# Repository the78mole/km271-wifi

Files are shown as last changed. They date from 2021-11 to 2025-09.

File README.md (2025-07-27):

# KM271-WiFi (WiFi enabled replacement for the KM271)

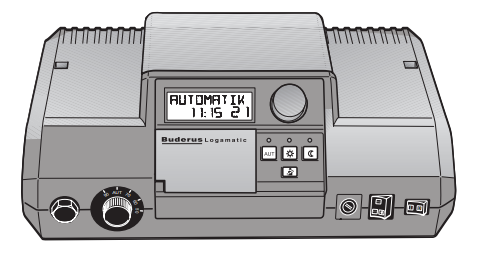
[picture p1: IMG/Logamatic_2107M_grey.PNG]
Buderus Logamatic 2107 M grey


    
    

If you just received a module, you can find help with installation here:

  - [Getting Started Guide](DOC/Getting_Started.md)
  - [Erste Schritte](DOC/Erste_Schritte.md)

This piece of hardware is a direct replacement for the Buderus KM271 to control a buderus heating system with Logamatic 2107 controller board. Maybe other controllers are supported. Please file an issue (or better a PR) if you have my module running in other Buderus heating controllers, so I can add them here.

This hardware and its documentation is released under the *TAPR Open Hardware License* Version 1.0 (May 25, 2007). 
A [copy of the license](LICENSE.txt) is included here or can be accessed in multiple formats on [tapr.org](https://tapr.org/the-tapr-open-hardware-license/). 

For more details, have a look in the:

  * [hardware description](DOC/Hardware%20Description.md)
  * [interactive BOM](https://htmlpreview.github.io/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)

If you bought the board in my tindie store, you could find a how-to to get it running [here](https://the78mole.de/projects/km271-wifi-howto/)

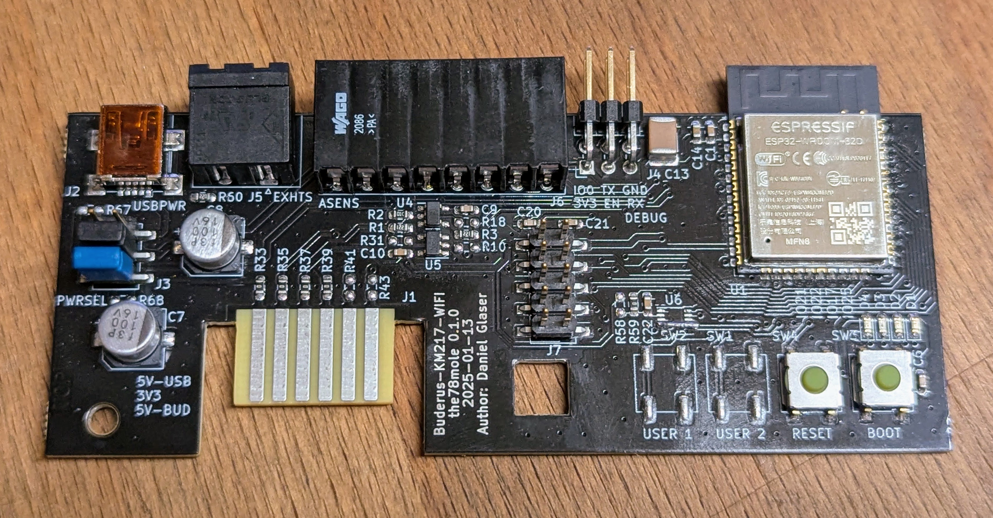
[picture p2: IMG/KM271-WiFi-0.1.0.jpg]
KM271-WiFi_0.1.0


## Extensions

There is now an Extension to add wired Ethernet to the board. The prototype already works, availability in tindie store will still take some time...

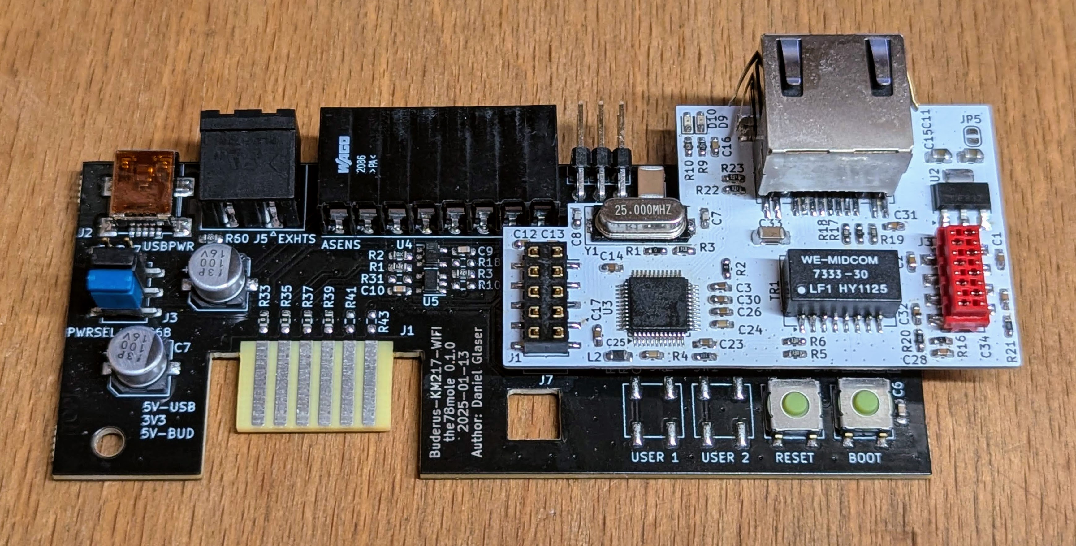
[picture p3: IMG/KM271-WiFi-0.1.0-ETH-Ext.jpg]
KM271-WiFi_0.1.0_ETH-Ext


## Improvements / ToDo

 * Add a OneWire temperature Sensor on the board itself
 * Fix a minor bug with external I2C pull-up (tie them to PCA9306 selectable supply)

## Firmware Management

This project includes a comprehensive firmware management system for easy firmware updates and batch production:

### 🚀 Quick Start

```bash
cd FW
./setup-dev.sh                                    # Setup development environment
uv run scripts/flash_firmware.py                  # List available firmware
uv run scripts/flash_firmware.py blinkenlights    # Flash single device
```

### 📦 Available Firmware Options

- **blinkenlights** - Local PlatformIO test project for hardware validation  
- **km271-esphome** - ESPHome-based KM271 WiFi replacement ([the78mole/ESPhome-KM271-WiFi](https://github.com/the78mole/ESPhome-KM271-WiFi))
- **dewenni-km271** - Feature-rich KM271 firmware ([dewenni/ESP_Buderus_KM271](https://github.com/dewenni/ESP_Buderus_KM271))

All firmware images are automatically downloaded and prepared for flashing using the management scripts.

### 🏭 Batch Production

For manufacturing multiple units:

```bash
uv run scripts/flash_firmware.py blinkenlights --loop
```

- Flash device → Connect next device → Press any key to continue
- Press 'n' to stop and show statistics
- Supports both ESC and 'n' for stopping

### 📖 Documentation

See [`FW/README.md`](FW/README.md) for detailed firmware management documentation, including:

- Setup instructions
- Script usage examples  
- Troubleshooting guide
- Batch production workflows

## 5V Supply Calibration

I decided to set the multiplier very far off the actual value, to make it clear, that you need to calibrate it due to the inaccurate/bad design of the ESP32 ADC with a quite low input impedance and general error.
To calibrate the Buderus 5V voltage monitor, you need to first find out the YAML section of your ESPhome device. It should look like the following:

```yaml
  - platform: adc
    pin: 36
    unit_of_measurement: "V"
    name: "KM217 5V Supply"
    accuracy_decimals: 2
    update_interval: 5s
    attenuation: 6dB
    filters:
      - multiply: 28.1826
      - throttle_average: 60s
```

Now look at the readout of your sensor, say it is 47.3V and measure the real voltage of the 5V supply (e.g. Pin 1 to 7 on the sensor header), say you measure 4.9V. Use the multiplier from your YAML and do the following calculation:

    4.9V / 47.3V * 28.1826 = 2.9196

Replace the multiplier by the calculated value and you will get more exact values, close to the 5V.

## Additional Information

  - [Moles Blog - Reverse Engineering KM271](https://the78mole.de/reverse-engineering-the-buderus-km217/)
  - [Moles Blog - KM271-WiFi Project](https://the78mole.de/projects/km271-wifi-howto/)
  - [KM271-WiFi ESPhome Project (GitHub)](https://github.com/the78mole/ESPhome-KM271-WiFi)
  - [KM271-WiFi WebTools (Flashing)](https://the78mole.github.io/ESPhome-KM271-WiFi/)
  - [KM271-Firmware ESPhome Component (GitHub)](https://github.com/the78mole/esphome_components)

You can buy the module on [Tindie](https://www.tindie.com/products/the78mole/buderus-km217-wifi-replacement/) (if available).

## Star History

Star History Chart (https://www.star-history.com/#the78mole/km271-wifi&Date)

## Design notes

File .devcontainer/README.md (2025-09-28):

# KM217 Hardware Development Environment

This DevContainer provides a complete hardware development environment for the KM217 project using a pre-built Docker image for optimal performance and fast startup.

## 🚀 Quick Start

1. Open this folder in VS Code
2. Click "Reopen in Container" when prompted
3. Container starts in ~30 seconds using `ghcr.io/the78mole/kicaddev:1.6.0`

## ✨ Features Included

- **KiCad 9.0.3**: Latest PCB design tools with full library support
- **Python 3.12.3**: Complete development environment with hardware packages
- **PCB Tools**: PCBDraw for visualization, KiKit for panelization
- **Development**: Git, VS Code extensions, debugging tools
- **GUI Support**: X11 forwarding for native KiCad GUI experience

## 🏗️ DevContainer Structure

```
.devcontainer/
├── devcontainer.json        # Main configuration
├── README.md               # This documentation
├── STATUS.md               # Current status and notes
└── test-devcontainer.sh    # Validation script
```

## � Available Tools

### KiCad 9.0.3 Suite
- **Schematic Editor**: Complete circuit design
- **PCB Editor**: Layout with advanced routing
- **3D Viewer**: Realistic board visualization
- **Symbol/Footprint Libraries**: Comprehensive component database

### Python Development
- **Python 3.12.3**: Latest stable Python
- **PCBDraw**: PCB visualization and documentation
- **KiKit**: PCB panelization and production automation
- **Hardware Libraries**: GPIO, I2C, SPI development tools

### Development Environment
- **Git**: Version control with full history
- **VS Code Extensions**: Python, Markdown, Linting pre-configured
- **X11 GUI**: Native Linux GUI application support

## 🚀 Usage Examples

### KiCad Development
```bash
# Open KiCad schematic editor
kicad myproject.kicad_pro

# Generate production files
kicad-cli pcb export gerbers --output production/ myproject.kicad_pcb

# Export schematic PDF
kicad-cli sch export pdf --output schematic.pdf myproject.kicad_sch
```

### PCB Visualization
```bash
# Create assembly diagram
pcbdraw myproject.kicad_pcb assembly.svg --side front

# Generate production visualization
pcbdraw myproject.kicad_pcb production.png --style builtin:set-blue-hasl
```

### PCB Panelization
```bash
# Create 2x2 panel with 2mm spacing
kikit panelize grid --space 2mm --gridsize 2x2 single.kicad_pcb panel.kicad_pcb
```
- **ImageMagick**: Image processing

## 📁 Directory Structure

The container sets up the following directories:
- `~/Documents/Hardware/` - Hardware projects
- `~/Documents/PCB/` - PCB designs  
- `~/Documents/Datasheets/` - Component datasheets
- `~/Documents/3D-Models/` - 3D model files
- `~/Templates/` - Document templates

## 🔧 VS Code Extensions

Pre-installed extensions for optimal workflow:
- Python development tools
- Markdown editing and preview
- Markdown PDF export
- YAML/JSON editing
- Jupyter notebook support

## 🚀 Getting Started

### Option 1: VS Code DevContainer (Recommended)
1. Open this project in VS Code
2. Install the "Dev Containers" extension
3. When prompted, click "Reopen in Container"
4. Wait for the container to build (first time only)
5. Start developing!

### Option 2: Local Docker Build
```bash
# Build the container locally
.devcontainer/build.sh

# Run manually
docker run -it --rm -v $(pwd):/workspaces hw-dev-container
```

### Quick Test
```bash
# Test Markdown to PDF conversion
cd ~/Templates
~/markdown2pdf.sh sample_hardware_doc.md

## 📋 Requirements

- Docker installed and running
- VS Code with Dev Containers extension
- X11 forwarding for GUI applications (automatically configured)

## ⚡ Performance

- **Startup Time**: ~30 seconds
- **Image Size**: 9.12GB (optimized)
- **Base System**: Ubuntu 24.04 LTS
- **Last Updated**: Regularly maintained

## 🔍 Troubleshooting

### GUI Applications Not Starting
If KiCad GUI doesn't open:
```bash
# Verify X11 forwarding
echo $DISPLAY

# Check if display is available
xdpyinfo | head
```

### Permission Issues
```bash
# Fix workspace permissions if needed
sudo chown -R vscode:vscode /workspaces
```

### Container Issues
```bash
# Test container functionality
./.devcontainer/test-devcontainer.sh

# Rebuild if needed
Docker: Rebuild Container (Ctrl+Shift+P)
```

## 📚 Additional Resources

- [KiCad Documentation](https://docs.kicad.org/)
- [PCBDraw Documentation](https://github.com/yaqwsx/pcbdraw)
- [KiKit Documentation](https://github.com/yaqwsx/kikit)

---

*Happy hardware development! 🛠️*

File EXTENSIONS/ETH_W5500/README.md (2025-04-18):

# Ethernet Module W5500

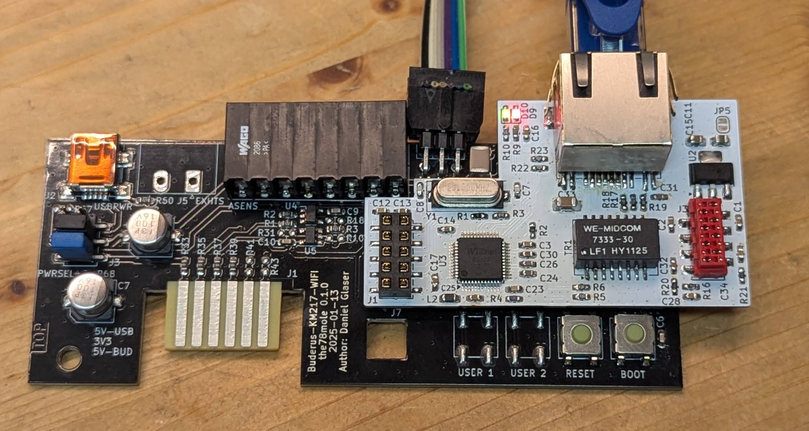
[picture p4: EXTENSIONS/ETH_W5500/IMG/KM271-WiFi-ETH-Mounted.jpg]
Extension mounted


The extension itself looks like this:

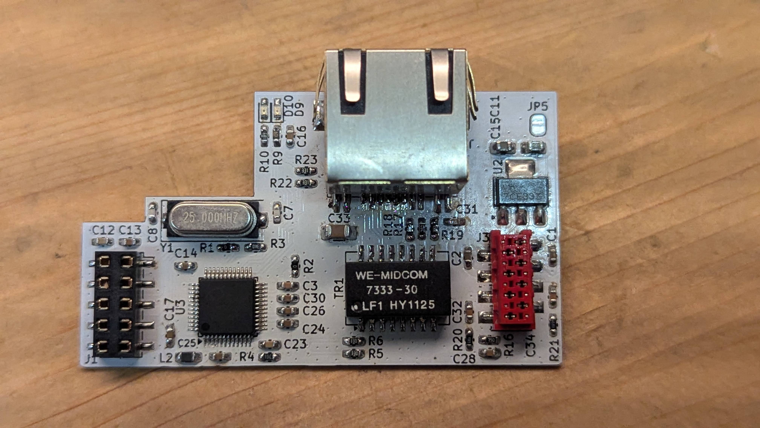
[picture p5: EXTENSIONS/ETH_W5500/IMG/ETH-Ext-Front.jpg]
ETH-Ext-Front

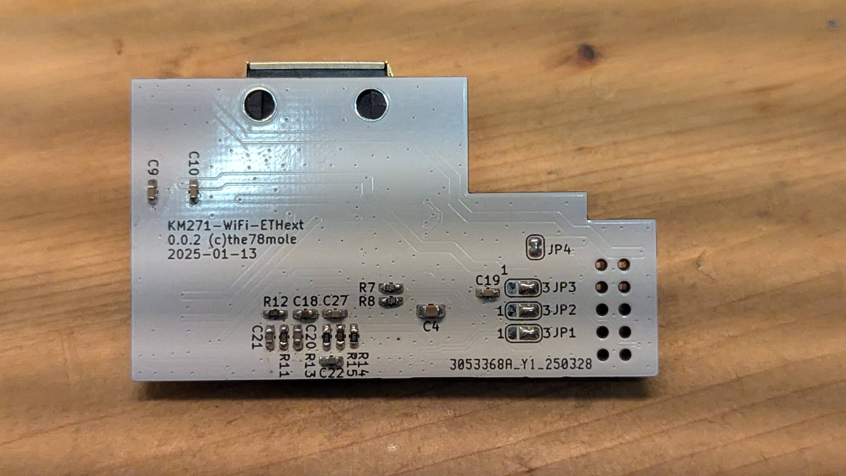
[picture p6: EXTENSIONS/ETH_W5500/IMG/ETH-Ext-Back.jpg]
ETH-Ext-Back


## Intro

To achieve wired connectivity with the KM271-WiFi (e.g. in concrete basements without any WiFi), we decided to
develop an Ethernet-Extension module, that is attached on the EXT (J7) connector via SPI interface.

For KM271-WiFi 0.1.0, you need to add a tiny fix-bridge to make it working.

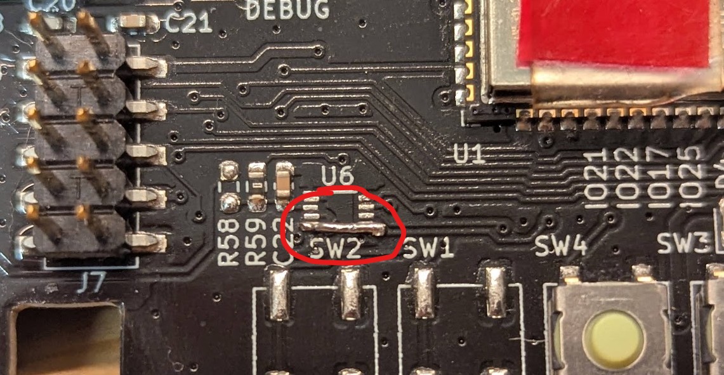
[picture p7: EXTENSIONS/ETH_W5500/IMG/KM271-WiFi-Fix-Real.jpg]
Fix-Bridge

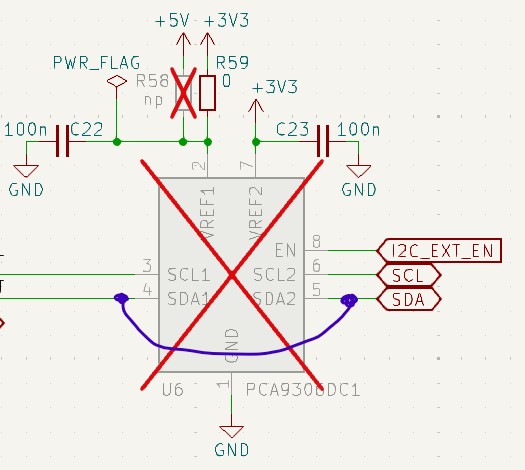
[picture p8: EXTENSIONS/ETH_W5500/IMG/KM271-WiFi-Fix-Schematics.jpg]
Fix-Schematic


Alternatively, when not experienced with soldering, you can add a wire to the ESP and the connector foot, but you need to use an insulated one:

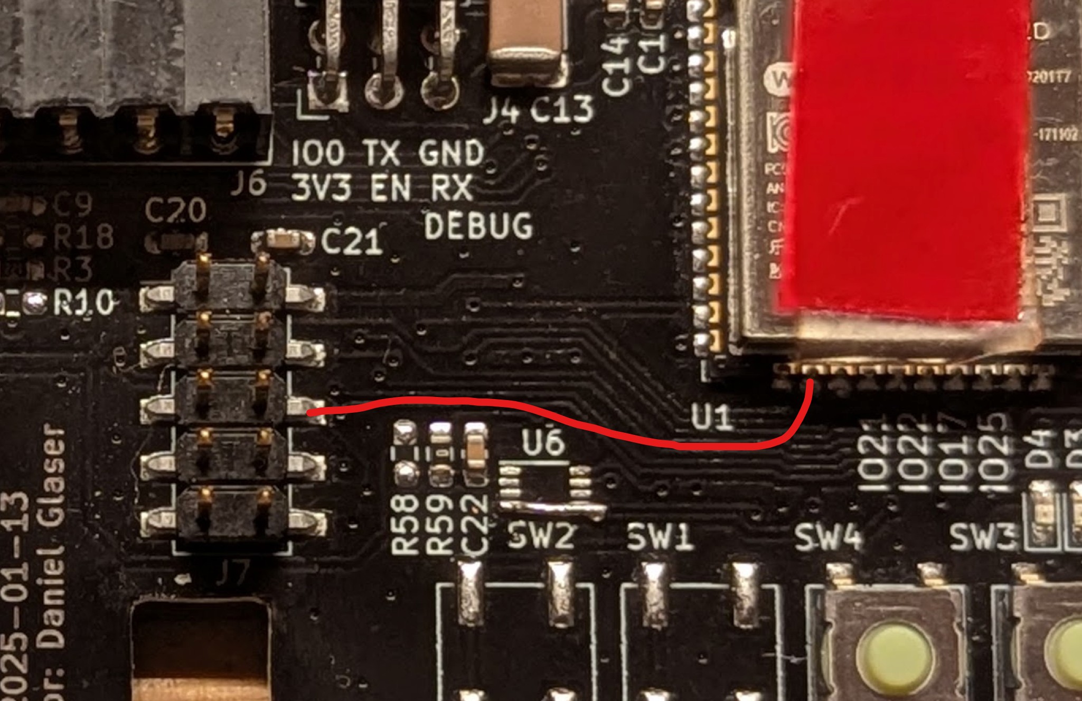
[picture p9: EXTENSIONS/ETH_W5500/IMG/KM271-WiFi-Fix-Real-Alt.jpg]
Fix-Wire


While it is also possible to connect a W5500 Ethernet module to the Board or a generic ESP32 using Du-Pont wires
it is not suggested due to instable operation.

## ETH-Ext Module: 

### Installation

The module needs to be mechanically fixed to and electrically insulated well from the KM271-WiFi. The space is quite dense and the easiest option is, to use some acrylic adhesive to attach it to the ESP32-WROOM-Module.

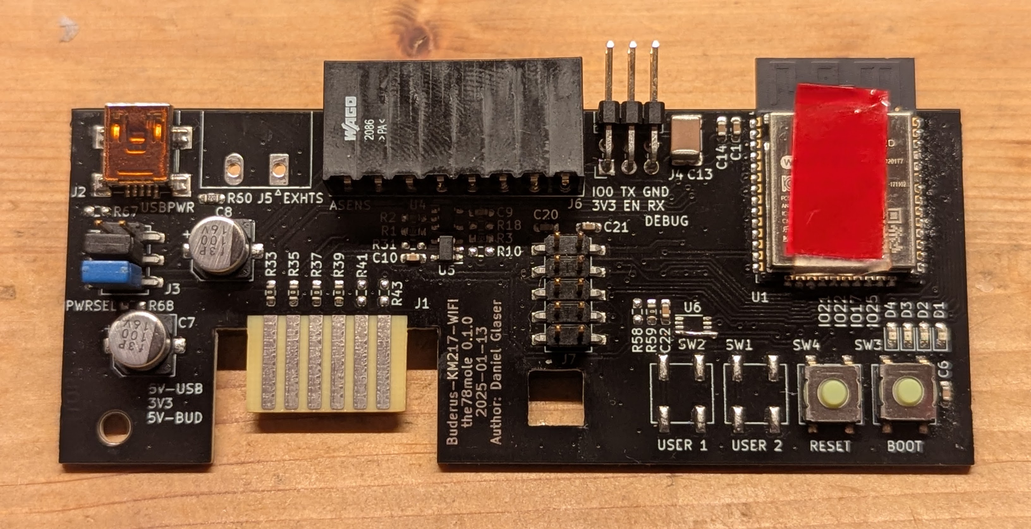
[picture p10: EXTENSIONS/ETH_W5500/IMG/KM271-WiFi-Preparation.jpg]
Prep KM271-WiFi


When ordering the ETH-Extension from Tindie, there is already an adhesive attached to the bootom of the Extension. Just remove the protective foil and mount it on the KM271-WiFi.

### ESPhome

For ESPhome, you need to add some configuration to the ESPhome YAML file:

```yaml
# Example configuration entry for SPI chips
ethernet:
  type: W5500
  clk_pin: 18
  mosi_pin: 23
  miso_pin: 19
  cs_pin: 15
  interrupt_pin: 14
  reset_pin: 13
```

Refer also to the [ESPhome documentation on wired ethernet](https://esphome.io/components/ethernet.html).

## DIY: W5500 Hardware Connection to KM271-WiFi

Dewenni built up a wired prototype with some W5500-Module, you can buy on aliexpress or almost anywhere else. He used the following setup for testing. This was the base for my own developed custom extension.

This is for the 0.0.6 and newer Boards.

| Signal | GPIO | Pin (J7) |
|---|---|---|
| VCC	 | | J7.2 |
| GND	 | | J7.10 |
| CLK | 18	| J7.9 |
| MOSI | 23 | J7.7 |
| MISO | 19 | J7.5 |
| CS | 15 | J7.3 |
| INT | 14 | J7.8 |
| RST | 13 | J7.6 |

Here's how it looks like with an external W5500-Module:

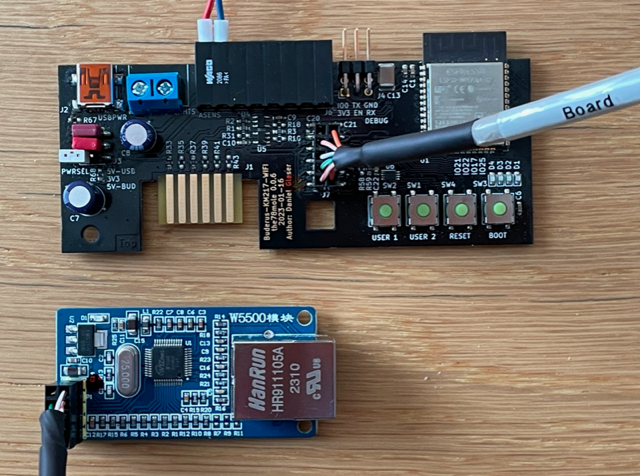
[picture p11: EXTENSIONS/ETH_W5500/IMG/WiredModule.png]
Experimental-WireUp


A custom PCB with W5500 will soon be available...

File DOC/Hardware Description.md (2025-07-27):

# KM271/KM217 WiFi

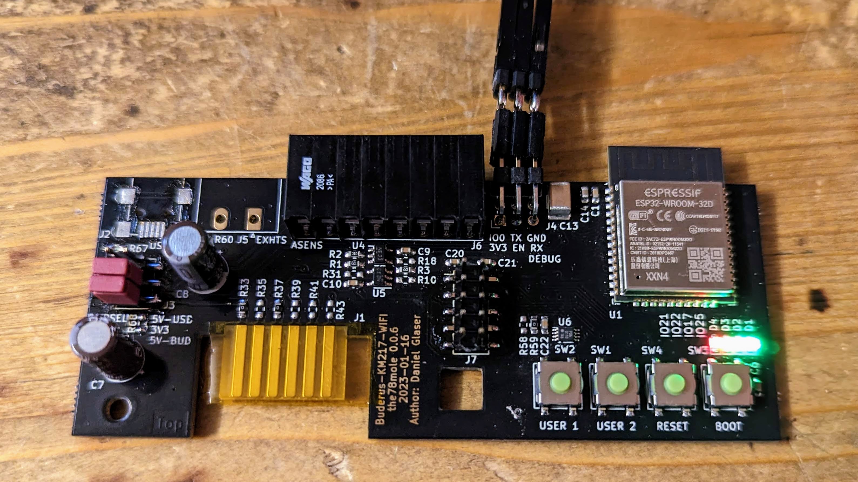
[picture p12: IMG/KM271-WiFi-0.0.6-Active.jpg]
KM271-WiFi mostly populated


The current board as of version 0.0.6 got a bit more complicated than earlier versions. It was extended by many features requested from the community. I will explain the features and their options in the following parts.

First of all, KM271 and KM217 is totally the same. The KM271 is the original RS232 extension from Buderus and it was my fault, having a typo here in the early beginning, when first releasing the module to the public. Now many file names have the KM217 in their name and changing it would simply be a nightmare... So just call it as you like it :-) 

# Preparation and Installation of the Module

After unpacking the module, first thing you need to do is break off the two handling edges of the PCB. These are left-overs from manufacturing and I keep them attached, as they give additional protection to the edges of the board during transport. You can use a finger nail file to remove shrap edges.

You also need to remove the protective foil from the edge connector. These foils protect the contacts from solder tin during reworks (when applying the selected order options) and also from scratches to and oxidation of the finger contacts.

Now check, if the power select header (if populated) has the correct jumper settings (see section "Power Supply Options" section). When done, insert the card into your Buderus control unit. Detailed instructions on how to connect the board to your WiFi and Home Assistant can be found here: <a href="http://bit.ly/3IWEZ5z">http://bit.ly/3IWEZ5z</a>

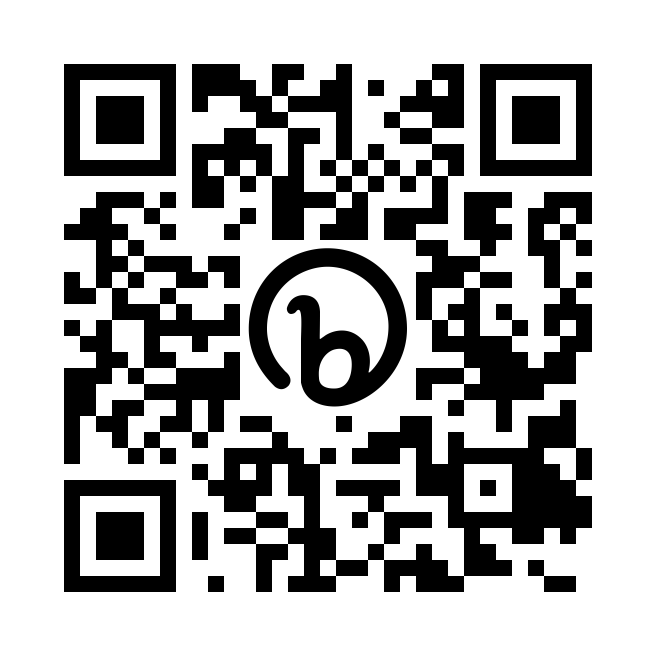
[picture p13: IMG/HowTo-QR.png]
HowTo QR


In a few words, the path with ESPhome service running e.g. as a Home Assistant add-on is as follows:

- Power up the board with following options (if populated) by
  - inserting the module into the Buderus control unit
  - (optional) through USB connector (set J3 correctly)
  - (optional) through 3.3V on the debug, extension or sensor header
  - (optional) through 5V on the sensor header
- Wait for at least one minute for the fallback WiFi-AP to come up
- If you use your smartphone to connect: Switch of the mobile internet connection (3G/4G/LTE)
- Connect your Smartphone or PC to the Fallback WiFi network
- Your smartphone tells, that you need to login to access internet (follow this)
- You will be forwarded to the ESP inital configuration page (see image below)
- Select your home WiFi from the list of the page and enter your WiFi credentials
- Press `Save` to apply the settings
- Watch the Home Assistant Web UI for a notification to appear
- Follow this notification and select `Configure` for the ESPhome device that was found
- Now you can enter the ESPhome Web UI, adjust the YAML file to your needs and do an OTA firmware update

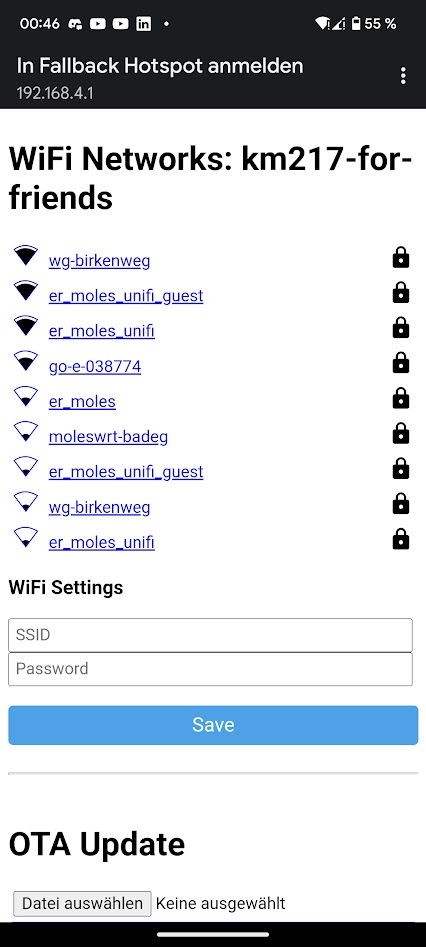
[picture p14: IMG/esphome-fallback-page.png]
Fallback Login


## Power Supply Options

When you receive the assembled board, it will be powered by the Buderus control unit by default. When there is no power supply header installed, two zero-ohm resistors select the supply:
  - Bridge from LDO output  to 3.3V of ESP
  - Bridge from Buderus 5V to the LDO input

If the power select header (J3) is installed, the two zero-ohm resistors are not populated. Therefore, two jumpers take over. These exactly mimic the behaviour of the zero-ohm resistors, when the board was assembled by me. This means in turn, even when a USB connector (J2) is assembled, the jumper configuration defaults to the Buderus supply, because I already had support requests complaining about non-functional boards with no USB power applied but jumpers set to USB supply.

But since some of the Buderus Heating Control units seem to have a weak power supply, some of the users of my extension suffer from, I added a USB power connector [Würth 65100516121](https://www.we-online.com/en/components/products/COM_SMT_MINI_TYPE_B_HORIZONTAL#65100516121) or [Reichelt USB BWM SMD](https://www.reichelt.de/usb-einbaubuchse-b-mini-gew-smd-montage-usb-bwm-smd-p52003.html) and the possibility to cut the supply from the 5V from Buderus. I'm not sure, if this is a problem of certain controllers equipped with a ton of original extensions or just scattering of good and bad supplies, but as soon as you attach other power hungry extensions to my board (like LC displays, many sensors,...), you should make use of this external power option.

For this purpose, I added a power select pin header (J3) with jumpers for the two 5V options (top = USB, bottom = Buderus) and if you want to supply 3.3V, you can cut-off the 3.3.V-LDO from the circuit with the middle Jumper.

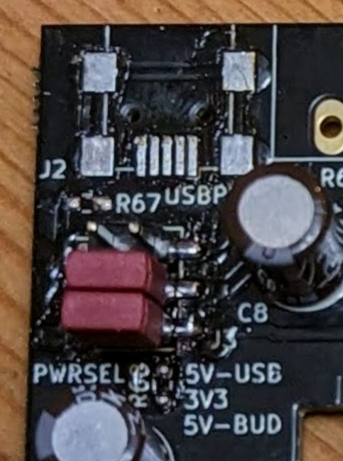
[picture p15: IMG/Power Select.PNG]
Power Select

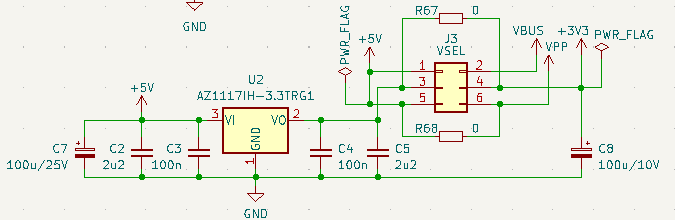
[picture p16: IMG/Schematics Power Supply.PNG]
Power Supply


If you populate the power select header yourself, do not forget to remove the two resistors R68 and R67.

## I2C

The I2C bus on the board is divided into two parts. The internal one running on 3.3V and an external one separated by a PCA9306 level shifter. 

### Internal I2C

The internal I2C parts are not soldered by default. One part is the EEPROM, another is the I2C-OneWire-Bridge. The GPIOs of the ESP32 used for it are:

| ESP32 Pin | Signal | Description |
|---|---|---|
| IO16 | SCL | I2C Clock Signal |
| IO13 | SDA | I2C Data Signal |
| IO14 | nINT | I2C Low-Active Open-Drain Interrupt Signal 3.3V !!! |
| IO12 | I2C_EXT_EN | Enable (this is the EN input of the PCA9306 level-shifter |

#### I2C EEPROM

The EEPROM is meant to store persistent settings, that shall survive a full erase of the ESP32 flash and to persistently store data that is changed frequently and would damage the flash NVM quickly. Since my ESPhome firmware makes no use of it, I decided to not populate this, but keep other makers the opportunity to easily add one.

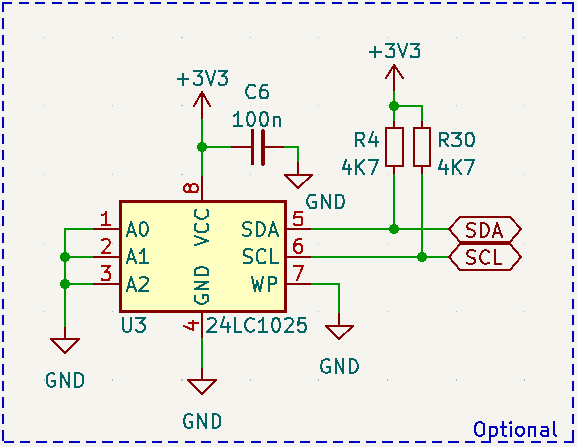
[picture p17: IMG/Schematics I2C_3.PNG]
I2C Part 3


#### I2C-OneWire Bridge

Since I had a lot of positive experience using the OneWire bridge devices in the past, having more range than a GPIO-based solution, to be able to drive the bus with strong power, sharpening the rising edge with strong pull-up and release the firmware from many burdens (e.g. the search algorithm), I decided to add such a bridge to the board as an option. Unfortunately, ESPhome has not yet a component to support it. Maybe I'll develop one sooner or later. Feel free to take the challenge :-)

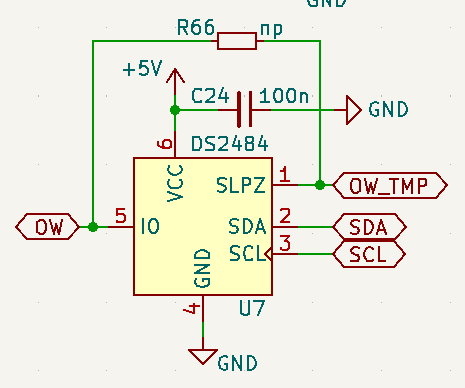
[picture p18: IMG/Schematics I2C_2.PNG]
I2C Part 2


### External I2C 

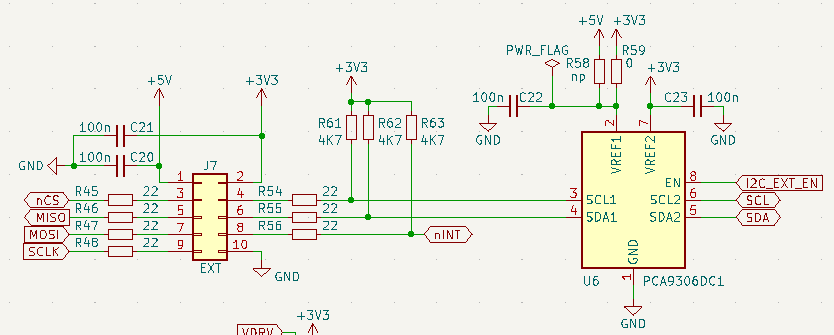
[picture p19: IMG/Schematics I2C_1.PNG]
I2C Part 1


The PCA9306 can be enabled by IO12 of the ESP32. The output voltage levels can be adjusted to your needs. By default, it is also tied to 3.3V, but moving the 0 Ohm resitance from R59 to R58, it can be set to 5V. In turn, the Pull-Ups R61 and R62 need to be unsoldered and replaced by Pull-Ups to 5V externally (this is a HW bug, I will fix in upcoming releases by tying them to the selectable supply of the PCA9306)

## OneWire

One wire is a very versatile bus, invented by Dallas, aquired by Maxim-IC and now is owned by Analog Devices. Nevertheless, still today new chips are released, extending the functionality of the OneWire bus more and more. The most widely known devices are the temperature sensors, namely the DS18B20. Up to 85°C, they do not even require a power supply and run completely from bus power. You can almost connect as many OneWire devices to the bus, as you want. There also exist switches, that can split your bus into segments and extend the range even further.

To address this wide spread sensors appropriately, I added an extension header to easily connect such devices and I also added a OneWire bus master (also known as I2C-OneWire-Bridge) to make even more use of it. Here are the OneWire relevant Pins:

| ESP32 Pin | Signal | Description |
|---|---|---|
| IO32 | OW_TMP |This is the direct path of the GPIO to OW, when you do not use the I2C-Bridge, if you use a bridge, it controls the bridges sleep mode |
| IO16 | SCL |the SCL of the I2C to connect the bridge, unused for direct GPIO-OW |
| IO13 | SDA |the SDA of the I2C to connect the bridge, unused for direct GPIO-OW |

The relevant parts of the OneWire feature are as follows:

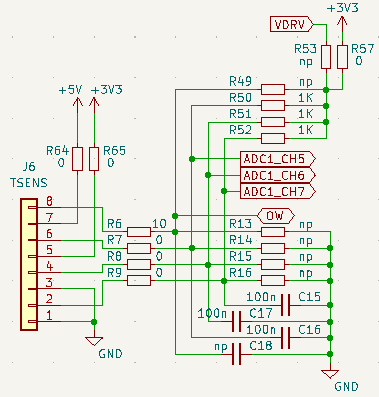
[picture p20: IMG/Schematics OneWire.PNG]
OneWire selection on J6

I2C Onewire Bridge

If you want to use OneWire directly on ESP32 GPIO, you first need to fit in a 0 Ohm R66. With this, you can easily drive OneWire from IO. Additionally you need to populate R49 with an appropriate resistor to serve your needs. Depending on the bus load, the length and the devices in general, you should always try out different values. In my case (with relatively short lines), 1K often serverd well. But I usually tend to supply the devices with a seperate power rail (3.3 or 5V), since the temperature sensors do not work with parasite power above 85°C, which can be quite common in heating applications (oil, gas burners, wood stoves, solar).

To decide for a good value, you should consult the 1-wire applications notes for that:

  * [Guidelines for Reliable Long Line 1-Wire Networks](https://www.analog.com/en/technical-articles/guidelines-for-reliable-long-line-1wire-networks.html)
  * [1-Wire Extended Network Standard](https://www.analog.com/en/design-notes/1wirereg-extended-network-standard.html)

## Extension Pin Header

Due to many requests (e.g. to attach a small display), I added an extension pin header to the board, that carries I2C and SPI and two helper signals. This header can be quipped with a simple flat ribbon cable or a custom PCB. Feel free to create extensions and post me your creations (preferred by Pull-Requests to this repo, added here with a link to the project :-). 

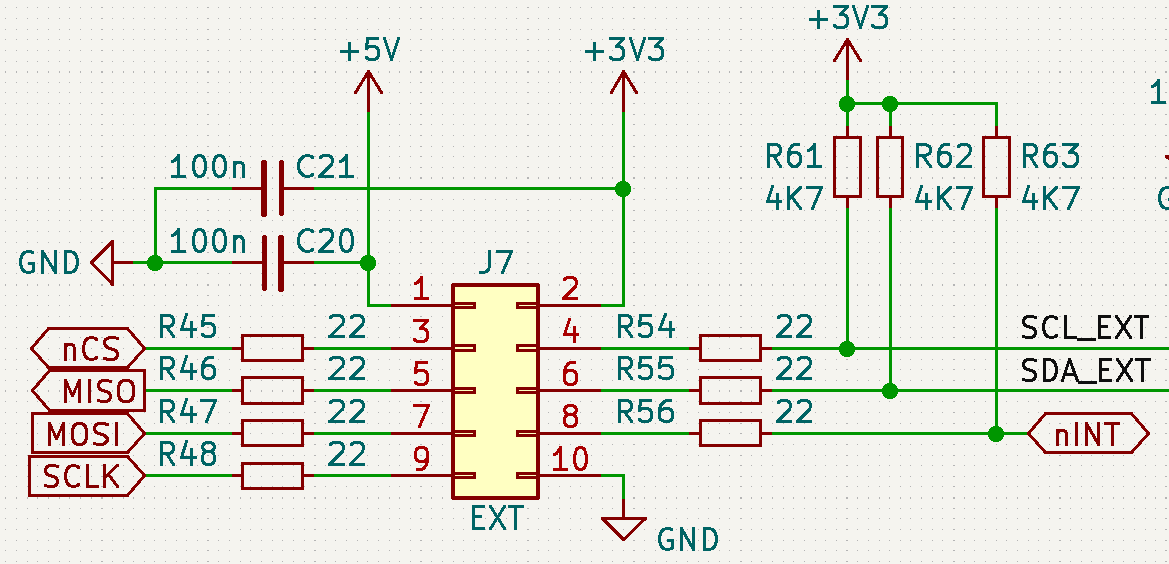
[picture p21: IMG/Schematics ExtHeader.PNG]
Extension Header


| Header | ESP32 Pin | Signal | Description |
|---|---|---|---|
| 1 | (ADC1 CH0)  | +5V | +5V Supply from USB or Buderus, depending on Power Select |
| 2 | (VDD) | +3V3 | +3.3V Supply |
| 3 | IO15 | nCS | SPI Chip Select, active low |
| 4 | IO16 | SCL (ext) | SCL of the I2C, gated by I2C_EXT_EN (IO12) |
| 5 | IO19 | MISO | SPI MISO signal |
| 6 | IO13 | SDA (ext) | SDA of the I2C, gated by I2C_EXT_EN (IO12) |
| 7 | IO23 | MOSI | SPI MOSI signal |
| 8 | IO14 | nINT | I2C interrupt signal (attention !!! +3V3 !!!) |
| 9 | IO18 | SCLK | SPI clock signal |
| 10 | (GND) | GND | Ground signal of the whole module | 

## Extension Wire Connector

To make it easily possible to add other sensors (as the mentioned OneWire) attachable, I added a push wire connector to the board. The Type is a WAGO 2086-1208 that can be ordered e.g. from [Reichelt](https://www.reichelt.de/thr-leiterplattenklemme-druecker-1-5-mm-8-polig-wago-2086-1208-p327148.html) or any other good sorted electronics shop.

The connector provides +5V, +3.3V and GND. Additionally, the internal circuitry for Pin 2 (ADC1 CH7), 4 (ADC1 CH6) & 6 (ADC1 CH5) is populated by default, to have 1K Pull-Up to +3.3V and a 100 nF to GND. So if you attach a 10K NTC between Pin 1 & 2, you have a simple resistor divider to be measured by ADC1 Channel 7. From that measurement, the Resistance can be easily calculated and from that and the temperature relation of the NTC, the temperature in turn. For more details, see the [section on NTC temperature measurement of ESPhome](https://esphome.io/components/sensor/ntc.html). In ESPhome, you could simply chain the platforms ADC, Resistance and NTC to get a temperature sensor from that. 

This connector can also be used to supply power to the board for 5V and 3.3V.     

OneWire selection on J6

## DEBUG Connector

The debug connector is a very easy part. It simply breaks out the signals to program the ESP32 over serial interface. The module does not contain the IO0/EN/Reset circuitry, as it is standard to the ESP32dev boards. In turn, you have three options:

  * use another ESP32dev board to do the programming (a bit tricky to disconnect the wires to the original ESP)
  * use a ESP32 PROG board as sold for a few EUR almost anywhere (e.g. [Reichelt ESP-PROG](https://www.reichelt.de/programmieradapter-fuer-esp8266-esp32-esp-prog-p314517.html), you can get it also for around 10 EUR e.g. on [aliexpress](https://de.aliexpress.com/item/33048891555.html))
  * do the signalling manually with BOOT and RESET buttons of my board: When esptool is trying to connect, press BOOT and RESET together, releasing RESET at first

**Have some fun with your oil burner, until it gets retired by a heat pump** :-)

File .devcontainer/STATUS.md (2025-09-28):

# 🎯 DevContainer Setup - Complete! 

## Status: ✅ Ready for Development

The DevContainer environment for the KM217 hardware project is fully configured and tested.

### 🚀 What has been implemented:

1. **Pre-built Docker Image**: Using `ghcr.io/the78mole/kicaddev:1.6.0`
2. **Performance**: Startup time of ~30 seconds
3. **Simplified Structure**: Only essential configuration files
4. **Optimized Documentation**: Focus on essential features

### 📁 DevContainer Structure:

```
.devcontainer/
├── devcontainer.json        # Main configuration (Pre-built Image)
├── README.md               # Comprehensive documentation
├── STATUS.md               # Current status (this document)
└── test-devcontainer.sh    # Validation script
```

### 🔧 Available Tools in Container:

- **KiCad 9.0.3**: PCB design and schematic editor
- **Python 3.12.3**: Scripting and automation
- **PCBDraw**: PCB visualization and documentation
- **KiKit**: PCB panelization and fabrication output
- **Git**: Version control
- **VS Code Extensions**: Python, Markdown, Linting

### 🚀 Next Steps:

1. **Start DevContainer**: `code .` → "Reopen in Container"
2. **Hardware Development**: Open and edit KiCad projects
3. **Documentation**: Convert Markdown to PDF
4. **Fabrication**: PCB production data export

### ⚡ Performance:

- **Startup**: ~30 seconds (instead of 5-10 minutes)
- **Image Size**: 9.12GB (optimized)
- **Last Updated**: 10 hours ago

### 📝 Notes:

- DevContainer now uses pre-built image only for optimal performance
- X11 forwarding for GUI apps is automatically configured  
- Privileged mode enabled for hardware access
- Simplified structure without local build options

---

**Status**: ✅ **Production Ready**  
**Last Updated**: July 27, 2025, 13:45 CET

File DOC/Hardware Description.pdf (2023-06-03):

Hardware Description.md | 3.6.2023

# KM271/KM217 WiFi


The current board as of version 0.0.6 got a bit more complicated than earlier versions. It was extended by many features requested from the community. I will explain the features and their options in the following parts.

First of all, KM271 and KM217 is totally the same. The KM271 is the original RS232 extension from Buderus and it was my fault, having a typo here in the early beginning, when first releasing the module to the public. Now many file names have the KM217 in their name and changing it would simply be a nightmare... So just call it as you like it

# Preparation and Installation of the Module

After unpacking the module, first thing you need to do is break off the two handling edges of the PCB. These are left-overs from manufacturing and I keep them attached, as they give additional protection to the edges of the board during transport. You can use a finger nail file to remove shrap edges.

You also need to remove the protective foil from the edge connector. These foils protect the contacts from solder tin during reworks (when applying the selected order options) and also from scratches to and oxidation of the finger contacts.

Now check, if the power select header (if populated) has the correct jumper settings (see section "Power Supply Options" section). When done, insert the card into your Buderus control unit. Detailed instructions on how to connect the board to your WiFi and Home Assistant can be found here: http://bit.ly/3IWEZ5z

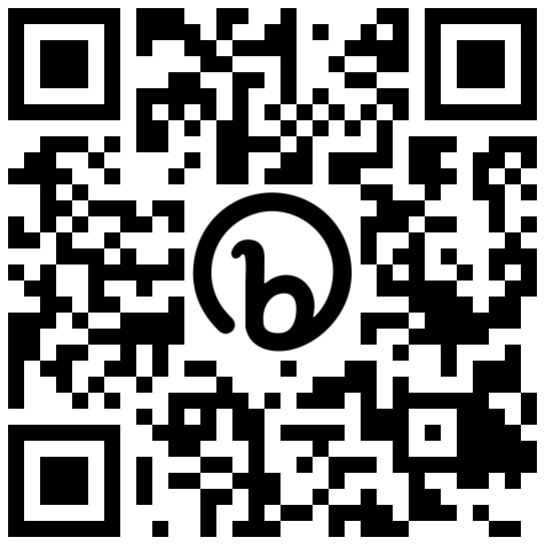
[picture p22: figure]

In a few words, the path with ESPhome service running e.g. as a Home Assistant add-on is as follows:

Power up the board with following options (if populated) by
inserting the module into the Buderus control unit
(optional) through USB connector (set J3 correctly)
(optional) through 3.3V on the debug, extension or sensor header
(optional) through 5V on the sensor header
Wait for at least one minute for the fallback WiFi-AP to come up
If you use your smartphone to connect: Switch of the mobile internet connection (3G/4G/LTE) Connect your Smartphone or PC to the Fallback WiFi network
Your smartphone tells, that you need to login to access internet (follow this)
You will be forwarded to the ESP inital configuration page (see image below)
Select your home WiFi from the list of the page and enter your WiFi credentials Press Save to apply the settings
Watch the Home Assistant Web UI for a notification to appear
Follow this notification and select Configure for the ESPhome device that was found
Now you can enter the ESPhome Web UI, adjust the YAML file to your needs and do an OTA firmware update

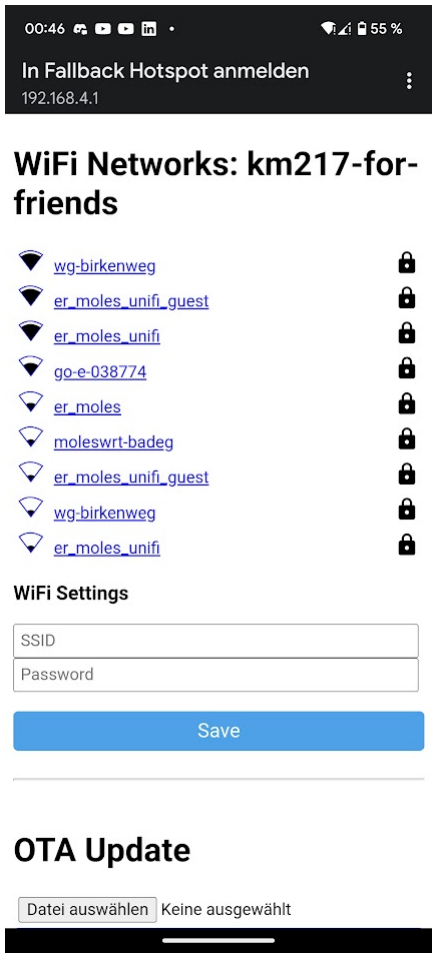
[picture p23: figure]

## Power Supply Options

When you receive the assembled board, it will be powered by the Buderus control unit by default. When there is no power supply header installed, two zero-ohm resistors select the supply:

Bridge from LDO output to 3.3V of ESP
Bridge from Buderus 5V to the LDO input

If the power select header (J3) is installed, the two zero-ohm resistors are not populated. Therefore, two jumpers take over. These exactly mimic the behaviour of the zero-ohm resistors, when the board was assembled by me. This means in turn, even when a USB connector (J2) is assembled, the jumper configuration defaults to the Buderus supply, because I already had support requests complaining about non-functional boards with no USB power applied but jumpers set to USB supply.

But since some of the Buderus Heating Control units seem to have a weak power supply, some of the users of my extension suffer from, I added a USB power connector Würth 65100516121 (https://www.we-online.com/en/components/products/COM_SMT_MINI_TYPE_B_HORIZONTAL#65100516121) or Reichelt USB BWM SMD (https://www.reichelt.de/usb-einbaubuchse-b-mini-gew-smd-montage-usb-bwm-smd-p52003.html) and the possibility to cut the supply from the 5V from Buderus. I'm not sure, if this is a problem of certain controllers equipped with a ton of original extensions or just scattering of good and bad supplies, but as soon as you attach other power hungry extensions to my board (like LC displays, many sensors,...), you should make use of this external power option.

For this purpose, I added a power select pin header (J3) with jumpers for the two 5V options (top = USB, bottom = Buderus) and if you want to supply 3.3V, you can cut-off the 3.3.V-LDO from the circuit with the middle Jumper.

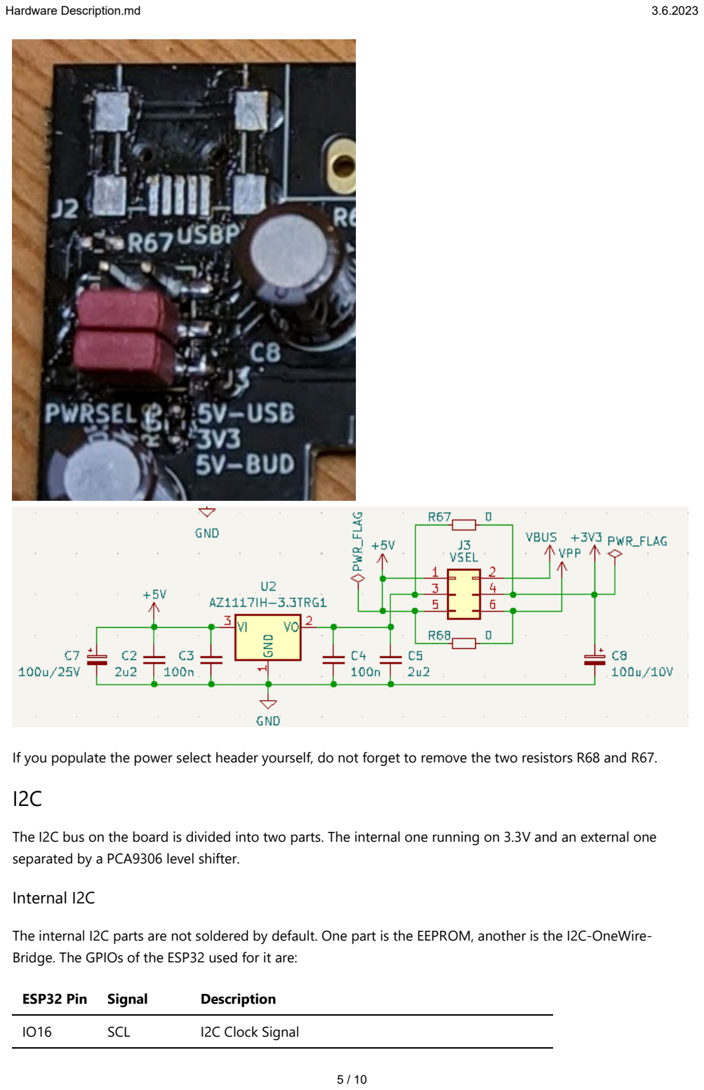
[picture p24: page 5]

If you populate the power select header yourself, do not forget to remove the two resistors R68 and R67.
I2C

The I2C bus on the board is divided into two parts. The internal one running on 3.3V and an external one separated by a PCA9306 level shifter.
Internal I2C

The internal I2C parts are not soldered by default. One part is the EEPROM, another is the I2C-OneWire-Bridge. The GPIOs of the ESP32 used for it are:

ESP32 Pin Signal | Description
IO16 | SCL | I2C Clock Signal

ESP32 Pin Signal | Description
IO13 | SDA | I2C Data Signal
IO14 | nINT | I2C Low-Active Open-Drain Interrupt Signal 3.3V !!!
IO12 | I2C_EXT_EN Enable (this is the EN input of the PCA9306 level-shifter

I2C EEPROM

The EEPROM is meant to store persistent settings, that shall survive a full erase of the ESP32 flash and to persistently store data that is changed frequently and would damage the flash NVM quickly. Since my ESPhome firmware makes no use of it, I decided to not populate this, but keep other makers the opportunity to easily add one.

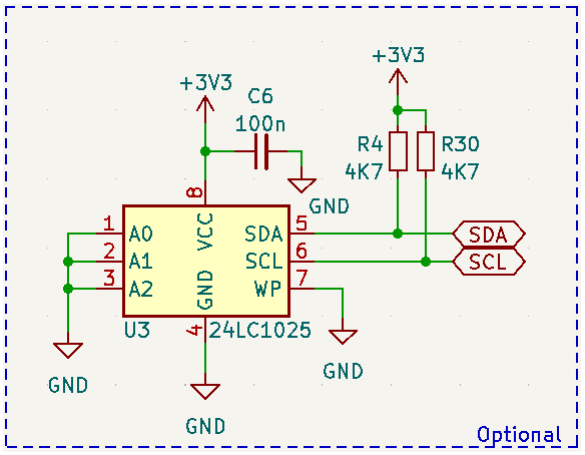
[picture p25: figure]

I2C-OneWire Bridge

Since I had a lot of positive experience using the OneWire bridge devices in the past, having more range than a GPIO-based solution, to be able to drive the bus with strong power, sharpening the rising edge with strong pull-up and release the firmware from many burdens (e.g. the search algorithm), I decided to add such a bridge to the board as an option. Unfortunately, ESPhome has not yet a component to support it. Maybe I'll develop one sooner or later. Feel free to take the challenge

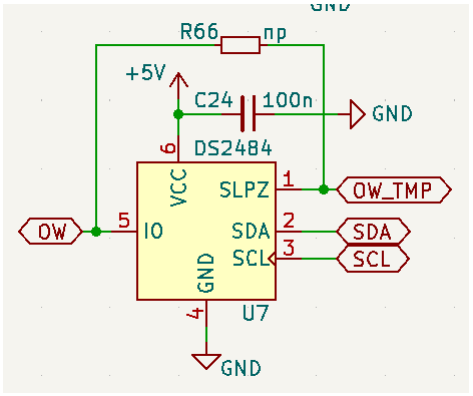
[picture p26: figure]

External I2C

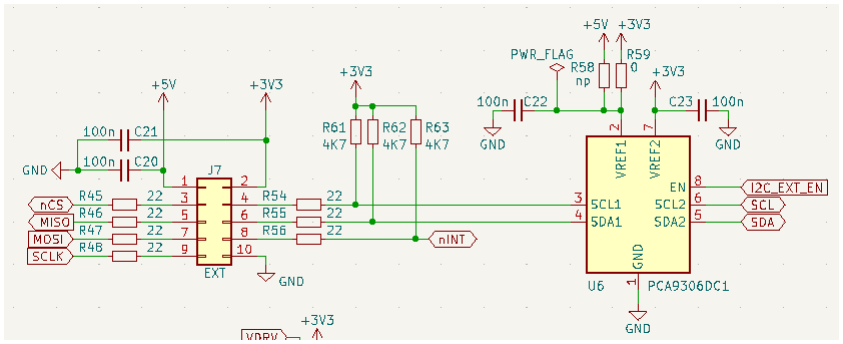
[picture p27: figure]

The PCA9306 can be enabled by IO12 of the ESP32. The output voltage levels can be adjusted to your needs. By default, it is also tied to 3.3V, but moving the 0 Ohm resitance from R59 to R58, it can be set to 5V. In turn, the Pull-Ups R61 and R62 need to be unsoldered and replaced by Pull-Ups to 5V externally (this is a HW bug, I will fix in upcoming releases by tying them to the selectable supply of the PCA9306)

## OneWire

One wire is a very versatile bus, invented by Dallas, aquired by Maxim-IC and now is owned by Analog Devices. Nevertheless, still today new chips are released, extending the functionality of the OneWire bus more and more. The most widely known devices are the temperature sensors, namely the DS18B20. Up to 85°C, they do not even require a power supply and run completely from bus power. You can almost connect as many OneWire devices to the bus, as you want. There also exist switches, that can split your bus into segments and extend the range even further.

To address this wide spread sensors appropriately, I added an extension header to easily connect such devices and I also added a OneWire bus master (also known as I2C-OneWire-Bridge) to make even more use of it. Here are the OneWire relevant Pins:

ESP32
Pin
| Signal | Description
IO32 | OW_TMP | This is the direct path of the GPIO to OW, when you do not use the I2C-Bridge, if you use a bridge, it controls the bridges sleep mode
IO16 | SCL | the SCL of the I2C to connect the bridge, unused for direct GPIO-OW
IO13 | SDA | the SDA of the I2C to connect the bridge, unused for direct GPIO-OW

The relevant parts of the OneWire feature are as follows:


If you want to use OneWire directly on ESP32 GPIO, you first need to fit in a 0 Ohm R66. With this, you can easily drive OneWire from IO. Additionally you need to populate R49 with an appropriate resistor to serve your needs. Depending on the bus load, the length and the devices in general, you should always try out different values. In my case (with relatively short lines), 1K often serverd well. But I usually tend to supply the devices with a seperate power rail (3.3 or 5V), since the temperature sensors do not work with parasite power above 85°C, which can be quite common in heating applications (oil, gas burners, wood stoves, solar).

To decide for a good value, you should consult the 1-wire applications notes for that:

Guidelines for Reliable Long Line 1-Wire Networks (https://www.analog.com/en/technical-articles/guidelines-for-reliable-long-line-1wire-networks.html)
1-Wire Extended Network Standard (https://www.analog.com/en/design-notes/1wirereg-extended-network-standard.html)

## Extension Pin Header

Due to many requests (e.g. to attach a small display), I added an extension pin header to the board, that carries I2C and SPI and two helper signals. This header can be quipped with a simple flat ribbon cable or a custom PCB. Feel free to create extensions and post me your creations (preferred by Pull-Requests to this
repo, added here with a link to the project | .


Header ESP32 Pin | Signal | Description
1 | (ADC1 CH0) +5V | +5V Supply from USB or Buderus, depending on Power Select
2 | (VDD) | +3V3 | +3.3V Supply
3 | IO15 | nCS | SPI Chip Select, active low
4 | IO16 | SCL (ext) | SCL of the I2C, gated by I2C_EXT_EN (IO12)
5 | IO19 | MISO | SPI MISO signal
6 | IO13 | SDA (ext) SDA of the I2C, gated by I2C_EXT_EN (IO12)
7 | IO23 | MOSI | SPI MOSI signal
8 | IO14 | nINT | I2C interrupt signal (attention !!! +3V3 !!!)
9 | IO18 | SCLK | SPI clock signal
10 | (GND) | GND | Ground signal of the whole module

## Extension Wire Connector

To make it easily possible to add other sensors (as the mentioned OneWire) attachable, I added a push wire connector to the board. The Type is a WAGO 2086-1208 that can be ordered e.g. from Reichelt (https://www.reichelt.de/thr-leiterplattenklemme-druecker-1-5-mm-8-polig-wago-2086-1208-p327148.html) or any other good sorted electronics shop.

The connector provides +5V, +3.3V and GND. Additionally, the internal circuitry for Pin 2 (ADC1 CH7), 4 (ADC1 CH6) & 6 (ADC1 CH5) is populated by default, to have 1K Pull-Up to +3.3V and a 100 nF to GND. So if you attach a 10K NTC between Pin 1 & 2, you have a simple resistor divider to be measured by ADC1 Channel
7. From that measurement, the Resistance can be easily calculated and from that and the temperature relation of the NTC, the temperature in turn. For more details, see the section on NTC temperature measurement of (https://esphome.io/components/sensor/ntc.html)

ESPhome. In ESPhome, you could simply chain the platforms ADC, Resistance and NTC to get a temperature (https://esphome.io/components/sensor/ntc.html) sensor from that.

This connector can also be used to supply power to the board for 5V and 3.3V.

## DEBUG Connector

The debug connector is a very easy part. It simply breaks out the signals to program the ESP32 over serial interface. The module does not contain the IO0/EN/Reset circuitry, as it is standard to the ESP32dev boards. In turn, you have three options:

use another ESP32dev board to do the programming (a bit tricky to disconnect the wires to the original ESP)
use a ESP32 PROG board as sold for a few EUR almost anywhere (e.g. Reichelt ESP-PROG, (https://www.reichelt.de/programmieradapter-fuer-esp8266-esp32-esp-prog-p314517.html) you can get it also for around 10 EUR e.g. on aliexpress) (https://de.aliexpress.com/item/33048891555.html)
do the signalling manually with BOOT and RESET buttons of my board: When esptool is trying to connect, press BOOT and RESET together, releasing RESET at first

Have some fun with your oil burner, until it gets retired by a heat pump

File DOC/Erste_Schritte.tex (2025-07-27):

% Options for packages loaded elsewhere
\PassOptionsToPackage{unicode}{hyperref}
\PassOptionsToPackage{hyphens}{url}
\documentclass[
  9pt,
]{extarticle}
\usepackage{xcolor}
\usepackage[a5paper, margin=0.5cm]{geometry}
\usepackage{amsmath,amssymb}
\setcounter{secnumdepth}{-\maxdimen} % remove section numbering
\usepackage{iftex}
\ifPDFTeX
  \usepackage[T1]{fontenc}
  \usepackage[utf8]{inputenc}
  \usepackage{textcomp} % provide euro and other symbols
\else % if luatex or xetex
  \usepackage{unicode-math} % this also loads fontspec
  \defaultfontfeatures{Scale=MatchLowercase}
  \defaultfontfeatures[\rmfamily]{Ligatures=TeX,Scale=1}
\fi
\usepackage{lmodern}
\ifPDFTeX\else
  % xetex/luatex font selection
  \setmainfont[]{Latin Modern Roman}
\fi
% Use upquote if available, for straight quotes in verbatim environments
\IfFileExists{upquote.sty}{\usepackage{upquote}}{}
\IfFileExists{microtype.sty}{% use microtype if available
  \usepackage[]{microtype}
  \UseMicrotypeSet[protrusion]{basicmath} % disable protrusion for tt fonts
}{}
\makeatletter
\@ifundefined{KOMAClassName}{% if non-KOMA class
  \IfFileExists{parskip.sty}{%
    \usepackage{parskip}
  }{% else
    \setlength{\parindent}{0pt}
    \setlength{\parskip}{6pt plus 2pt minus 1pt}}
}{% if KOMA class
  \KOMAoptions{parskip=half}}
\makeatother
\usepackage{longtable,booktabs,array}
\usepackage{calc} % for calculating minipage widths
% Correct order of tables after \paragraph or \subparagraph
\usepackage{etoolbox}
\makeatletter
\patchcmd\longtable{\par}{\if@noskipsec\mbox{}\fi\par}{}{}
\makeatother
% Allow footnotes in longtable head/foot
\IfFileExists{footnotehyper.sty}{\usepackage{footnotehyper}}{\usepackage{footnote}}
\makesavenoteenv{longtable}
\usepackage{graphicx}
\makeatletter
\newsavebox\pandoc@box
\newcommand*\pandocbounded[1]{% scales image to fit in text height/width
  \sbox\pandoc@box{#1}%
  \Gscale@div\@tempa{\textheight}{\dimexpr\ht\pandoc@box+\dp\pandoc@box\relax}%
  \Gscale@div\@tempb{\linewidth}{\wd\pandoc@box}%
  \ifdim\@tempb\p@<\@tempa\p@\let\@tempa\@tempb\fi% select the smaller of both
  \ifdim\@tempa\p@<\p@\scalebox{\@tempa}{\usebox\pandoc@box}%
  \else\usebox{\pandoc@box}%
  \fi%
}
% Set default figure placement to htbp
\def\fps@figure{htbp}
\makeatother
\setlength{\emergencystretch}{3em} % prevent overfull lines
\providecommand{\tightlist}{%
  \setlength{\itemsep}{0pt}\setlength{\parskip}{0pt}}
\usepackage{multicol}
\usepackage{graphicx}
\usepackage{wrapfig}
\usepackage[svgnames]{xcolor}
\usepackage{float}
\usepackage{caption}
\usepackage{ifthen}
\usepackage{enumitem}
\setlist{nosep}
\linespread{1.2}
\setlength{\columnsep}{1cm}
\newboolean{inlatex}
\setboolean{inlatex}{true}
\usepackage{bookmark}
\IfFileExists{xurl.sty}{\usepackage{xurl}}{} % add URL line breaks if available
\urlstyle{same}
\hypersetup{
  pdftitle={KM271-WiFi Schnellstart-Anleitung},
  pdfauthor={Daniel (the78mole) Glaser},
  hidelinks,
  pdfcreator={LaTeX via pandoc}}

\title{KM271-WiFi Schnellstart-Anleitung}
\author{Daniel (the78mole) Glaser}
\date{\today}

\begin{document}
\maketitle

\section{KM271-WiFi Schnellstart}\label{km271-wifi-schnellstart}

Dies ist eine kurze Anleitung zur Inbetriebnahme des KM271-WiFi-Moduls.

  \begin{wrapfigure}{r}{0.40\textwidth}
    \centering
    
    \caption{KM271-WiFi groeßtenteils bestueckt}
  \end{wrapfigure}

\subsection{Voraussetzungen}\label{voraussetzungen}

Überprüfe zunächst, ob alles wie bestellt vorhanden ist (von links nach
rechts):

\begin{itemize}
\tightlist
\item
  \textbf{J5} ist der Anschluss für den Abgastemperatursensor (das
  Gegenstück lag dem Paket bei, Farben können abweichen: schwarz oder
  grün)
\item
  \textbf{J6} ist der Anschluss für Sensorleitungen
\item
  \textbf{J4} ist der Debug-Anschluss zur Programmierung über eine
  serielle Verbindung
\end{itemize}

Je nach Bestellung und gewählten Optionen sind einige Anschlüsse
möglicherweise nicht bestückt. Die Ethernet-Erweiterung auf dem zweiten
Bild ist ein separates Modul, das ebenfalls in meinem Tindie-Shop
erhältlich ist.

  \begin{wrapfigure}{r}{0.40\textwidth}
    \centering
    
    \caption{KM271-WiFi mit Ethernet-Erweiterung}
  \end{wrapfigure}

Nun \textbf{prüfe, ob der PWRSEL-Header} wie im Bild gezeigt bestückt
ist. Der mittlere und der untere Jumper sollten gesteckt sein. Dies ist
die korrekte Variante für die \textbf{Versorgung über die
Buderus-Steuerung}. Wenn du das Modul \textbf{über USB versorgen}
willst, musst du den unteren Jumper (blau im Bild) nach oben versetzen.
Orientiere dich dabei an der Beschriftung unter dem Kondensator. Der
schwarze Jumper darf nur zum Flashen über die serielle Schnittstelle
entfernt werden.

Für die Ethernet-Erweiterung prüfe: J5 ist geschlossen, J4 ist offen,
und die Jumper J1 bis J3 sitzen auf den Positionen 2--3.

\subsection{Einbau}\label{einbau}

Wenn du Ethernet nutzen möchtest, ist jetzt der richtige Zeitpunkt, die
Ethernet-Erweiterung aufzustecken.

\begin{enumerate}
\def\labelenumi{\arabic{enumi}.}
\tightlist
\item
  Schalte die Buderus-Steuerung aus\\
\item
  Entferne die beiden Schrauben des Gehäuses und hebe es vorsichtig an\\
\item
  Biege die über dem KM271-Slot verlaufenden Kabel etwas nach oben,
  sodass das Modul seitlich eingeschoben werden kann\\
\item
  Richte das Modul in den Führungsschienen des KM271 aus und schiebe es
  nach unten\\
\item
  Drücke das Modul vorsichtig in den Steckplatz -- es rastet mit einer
  kleinen Lasche in die rechteckige Öffnung des KM271-Moduls ein (im
  Bild neben dem Flachsteckverbinder). Wenn du das Modul wieder
  entfernen möchtest, entriegle die Lasche mit einem Schraubendreher\\
\item
  Schließe ggf. weitere Sensoren an: Abgastemperaturfühler, Ölzähler,
  OneWire usw.\\
\item
  Setze das Gehäuse der Buderus-Steuerung wieder auf\\
\item
  Schalte die Steuerung wieder ein
\end{enumerate}

Auf dem Display der Buderus-Steuerung sollte nun ein neuer Eintrag
\texttt{ABGAS} oder \texttt{EXHAUST} erscheinen. Falls nicht, nutze das
Drehrad zur Navigation. Wenn du einen Abgastemperaturfühler
angeschlossen hast, wird dessen aktuelle Temperatur angezeigt. Falls
nicht, steht dort \texttt{-\/-\/-} -- das ist völlig in Ordnung.

Nun nimm dein Smartphone oder einen PC und suche nach dem WLAN
\texttt{Fallback\ Hotspot} (bei ESPhome) oder \texttt{ESP-Buderus-KM271}
(bei dewennis Firmware). Auf Android fragt das Gerät nach
10--20\,Sekunden, ob du verbunden bleiben möchtest (da keine
Internetverbindung vorhanden ist) -- bestätige mit \texttt{Ja}. Öffne
dann den Browser und rufe die Adresse http://192.168.4.1 auf. Manchmal
dauert es einige Minuten, bis eine Verbindung aufgebaut oder die Seite
geladen ist (vermutlich ein Bug in ESPhome). Bis zu diesem Punkt ist das
Vorgehen bei dewennis Firmware identisch -- sie reagiert meist nur etwas
schneller. Fahre jetzt mit dem passenden Kapitel zu deiner Firmware
fort.

\subsubsection{ESPhome-Konfiguration}\label{esphome-konfiguration}

Du solltest nun die Seite des Fallback-Hotspots sehen:

  \begin{wrapfigure}{r}{0.35\textwidth}
    \centering
    
    \caption{Fallback-Hotspot-Seite}
  \end{wrapfigure}

Wähle dein WLAN und gib das Passwort ein. Wenn du versehentlich das
falsche WLAN gewählt hast, ist es später schwierig, wieder Zugriff auf
das Board zu bekommen. In diesem Fall musst du das falsche WLAN
deaktivieren oder das Modul außerhalb der Reichweite bringen. Alternativ
kannst du das Modul aus der Buderus-Steuerung entfernen und per USB
versorgen und aus dem Empfangsbereich rausgehen (dazu den PWRSEL-Jumper
umsetzen). Danach kannst du die Einrichtung erneut starten.

Auf der Seite des Fallback-Hotspots kannst du auch eine neue Firmware
flashen -- allerdings \textbf{keine andere Firmware} (z.\,B. die von
dewenni).

Nach der Einrichtung sollte das Board in deinem ESPhome-Addon in Home
Assistant erscheinen. Du kannst nun die YAML-Konfiguration anpassen oder
so lassen, wie sie ist. Wenn eine neue Firmware verfügbar ist (z.\,B.
durch ein Update des Addons), kann diese in der Regel problemlos
eingespielt werden.

Das Gerät und seine Sensoren, Werte usw. findest du in Home Assistant
unter:\\
\textbf{Einstellungen → Geräte \& Dienste → ESPhome}

Weitere Informationen findest du hier:\\
https://github.com/the78mole/ESPhome-KM271-WiFi

\href{https://github.com/the78mole/ESPhome-KM271-WiFi}{\pandocbounded{}}

\subsubsection{Dewennis
MQTT-Konfiguration}\label{dewennis-mqtt-konfiguration}

Beim ersten Zugriff auf dewennis Web-Oberfläche solltest du zunächst die
GPIOs konfigurieren -- insbesondere, wenn du die Ethernet-Erweiterung
(ETH-Ext) verwenden willst, um das KM271-WiFi mit deinem Heimnetz zu
verbinden. Die GPIOs sind wie folgt:

\begin{longtable}[]{@{}lll@{}}
\toprule\noalign{}
Signal & GPIO & Pin (J7) \\
\midrule\noalign{}
\endhead
\bottomrule\noalign{}
\endlastfoot
VCC & & J7.2 \\
GND & & J7.10 \\
CLK & 18 & J7.9 \\
MOSI & 23 & J7.7 \\
MISO & 19 & J7.5 \\
CS & 15 & J7.3 \\
INT & 14 & J7.8 \\
RST & 13 & J7.6 \\
\end{longtable}

Abgesehen von der Ethernet-Konfiguration kannst du alle weiteren
Einstellungen auch nach dem Neustart vornehmen.

Danach musst du noch die GPIOs für die Verbindung zur Buderus-Steuerung
konfigurieren. Für das KM271-WiFi gibt es eine vordefinierte Option --
bitte wähle diese aus. Wenn du andere Hardware anschließen möchtest,
findest du hier die detaillierte Beschreibung:

\href{https://bit.ly/4jA7aHu}{\pandocbounded{}}

https://bit.ly/4jA7aHu

\begin{center}\rule{0.5\linewidth}{0.5pt}\end{center}

Für weitere Unterstützung kannst du meinem Matrix-Kanal beitreten:\\
https://matrix.to/\#/\%23molesblog:matrix.org

\begin{center}\rule{0.5\linewidth}{0.5pt}\end{center}

\textbf{Viel Spaß mit deinem Ölbrenner -- bis ihn die Wärmepumpe in
Rente schickt!}

\end{document}

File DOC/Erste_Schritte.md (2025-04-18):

---
title: "KM271-WiFi Schnellstart-Anleitung"
author: "Daniel (the78mole) Glaser"
---
# KM271-WiFi Schnellstart

Dies ist eine kurze Anleitung zur Inbetriebnahme des KM271-WiFi-Moduls.

KM271-WiFi groeßtenteils bestueckt

## Voraussetzungen

Überprüfe zunächst, ob alles wie bestellt vorhanden ist (von links nach rechts):

- **J5** ist der Anschluss für den Abgastemperatursensor (das Gegenstück lag dem Paket bei, Farben können abweichen: schwarz oder grün)
- **J6** ist der Anschluss für Sensorleitungen
- **J4** ist der Debug-Anschluss zur Programmierung über eine serielle Verbindung

Je nach Bestellung und gewählten Optionen sind einige Anschlüsse möglicherweise nicht bestückt. Die Ethernet-Erweiterung auf dem zweiten Bild ist ein separates Modul, das ebenfalls in meinem Tindie-Shop erhältlich ist.

KM271-WiFi mit Ethernet-Erweiterung

Nun **prüfe, ob der PWRSEL-Header** wie im Bild gezeigt bestückt ist. Der mittlere und der untere Jumper sollten gesteckt sein. Dies ist die korrekte Variante für die **Versorgung über die Buderus-Steuerung**. Wenn du das Modul **über USB versorgen** willst, musst du den unteren Jumper (blau im Bild) nach oben versetzen. Orientiere dich dabei an der Beschriftung unter dem Kondensator. Der schwarze Jumper darf nur zum Flashen über die serielle Schnittstelle entfernt werden.

Für die Ethernet-Erweiterung prüfe: J5 ist geschlossen, J4 ist offen, und die Jumper J1 bis J3 sitzen auf den Positionen 2–3.

## Einbau

Wenn du Ethernet nutzen möchtest, ist jetzt der richtige Zeitpunkt, die Ethernet-Erweiterung aufzustecken.

1. Schalte die Buderus-Steuerung aus  
2. Entferne die beiden Schrauben des Gehäuses und hebe es vorsichtig an  
3. Biege die über dem KM271-Slot verlaufenden Kabel etwas nach oben, sodass das Modul seitlich eingeschoben werden kann  
4. Richte das Modul in den Führungsschienen des KM271 aus und schiebe es nach unten  
5. Drücke das Modul vorsichtig in den Steckplatz – es rastet mit einer kleinen Lasche in die rechteckige Öffnung des KM271-Moduls ein (im Bild neben dem Flachsteckverbinder). Wenn du das Modul wieder entfernen möchtest, entriegle die Lasche mit einem Schraubendreher  
6. Schließe ggf. weitere Sensoren an: Abgastemperaturfühler, Ölzähler, OneWire usw.  
7. Setze das Gehäuse der Buderus-Steuerung wieder auf  
8. Schalte die Steuerung wieder ein

Auf dem Display der Buderus-Steuerung sollte nun ein neuer Eintrag `ABGAS` oder `EXHAUST` erscheinen. Falls nicht, nutze das Drehrad zur Navigation. Wenn du einen Abgastemperaturfühler angeschlossen hast, wird dessen aktuelle Temperatur angezeigt. Falls nicht, steht dort `---` – das ist völlig in Ordnung.

Nun nimm dein Smartphone oder einen PC und suche nach dem WLAN `Fallback Hotspot` (bei ESPhome, Passwort: `Z8zfajgxVvNw`) oder `ESP-Buderus-KM271` (bei dewennis Firmware). Auf Android fragt das Gerät nach 10–20 Sekunden, ob du verbunden bleiben möchtest (da keine Internetverbindung vorhanden ist) – bestätige mit `Ja`. Öffne dann den Browser und rufe die Adresse http://192.168.4.1 auf. Manchmal dauert es einige Minuten, bis eine Verbindung aufgebaut oder die Seite geladen ist (vermutlich ein Bug in ESPhome). Bis zu diesem Punkt ist das Vorgehen bei dewennis Firmware identisch – sie reagiert meist nur etwas schneller. Fahre jetzt mit dem passenden Kapitel zu deiner Firmware fort.

### ESPhome-Konfiguration

Du solltest nun die Seite des Fallback-Hotspots sehen:

Fallback-Hotspot-Seite

Wähle dein WLAN und gib das Passwort ein. Wenn du versehentlich das falsche WLAN gewählt hast, ist es später schwierig, wieder Zugriff auf das Board zu bekommen. In diesem Fall musst du das falsche WLAN deaktivieren. Alternativ kannst du das Modul aus der Buderus-Steuerung entfernen, aus dem Empfangsbereich rausgehen und das Modul per USB versorgen (dazu den PWRSEL-Jumper umsetzen). Danach kannst du die Einrichtung erneut starten.

Auf der Seite des Fallback-Hotspots kannst du auch eine neue Firmware flashen – allerdings **keine andere Firmware** (z. B. nicht die von dewenni).

Nach der Einrichtung sollte das Board in deinem ESPhome-Addon in Home Assistant erscheinen. Du kannst nun die YAML-Konfiguration anpassen oder so lassen, wie sie ist. Wenn eine neue Firmware verfügbar ist (z. B. durch ein Update des Addons), kann diese in der Regel problemlos eingespielt werden.

Das Gerät und seine Sensoren, Werte usw. findest du in Home Assistant unter:  
**Einstellungen → Geräte & Dienste → ESPhome**

Weitere Informationen findest du hier:  
https://github.com/the78mole/ESPhome-KM271-WiFi

QR (https://github.com/the78mole/ESPhome-KM271-WiFi)

### Dewennis MQTT-Konfiguration

Beim ersten Zugriff auf dewennis Web-Oberfläche solltest du zunächst die GPIOs konfigurieren – insbesondere, wenn du die Ethernet-Erweiterung (ETH-Ext) verwenden willst, um das KM271-WiFi mit deinem Heimnetz zu verbinden. Die GPIOs sind wie folgt:

| Signal | GPIO  | Pin (J7) |
|---|---|---|
| VCC | | J7.2 |
| GND | | J7.10 |
| CLK | 18 | J7.9 |
| MOSI | 23 | J7.7 |
| MISO | 19 | J7.5 |
| CS | 15 | J7.3 |
| INT | 14 | J7.8 |
| RST | 13 | J7.6 |

Abgesehen von der Ethernet-Konfiguration kannst du alle weiteren Einstellungen auch nach dem Neustart vornehmen.

Danach musst du noch die GPIOs für die Verbindung zur Buderus-Steuerung konfigurieren. Für das KM271-WiFi gibt es eine vordefinierte Option – bitte wähle diese aus. Wenn du andere Hardware anschließen möchtest, findest du hier die detaillierte Beschreibung:

https://bit.ly/4jA7aHu

QR (https://bit.ly/4jA7aHu)

---

Für weitere Unterstützung kannst du meinem Matrix-Kanal beitreten:  
https://matrix.to/#/#molesblog:matrix.org

---

**Viel Spaß mit deinem Ölbrenner – bis ihn die Wärmepumpe in Rente schickt!**


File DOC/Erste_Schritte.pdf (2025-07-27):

## KM271-WiFi Schnellstart-Anleitung

Daniel (the78mole) Glaser

### KM271-WiFi Schnellstart

Dies ist eine kurze Anleitung zur Inbetriebnahme des KM271-WiFi-Moduls.


Figure 1: KM271-WiFi groeßtenteils bestueckt

Voraussetzungen

Überprüfe zunächst, ob alles wie bestellt vorhanden ist (von links nach rechts):
- J5 ist der Anschluss für den Abgastemperatursensor (das Gegenstück lag dem Paket bei, Farben

können abweichen: schwarz oder grün)
- J6 ist der Anschluss für Sensorleitungen
- J4 ist der Debug-Anschluss zur Programmierung über eine serielle Verbindung

Je nach Bestellung und gewählten Optionen sind einige Anschlüsse möglicherweise nicht bestückt. Die Ethernet-Erweiterung auf dem zweiten Bild ist ein separates Modul, das ebenfalls in meinem Tindie-Shop erhältlich ist.
Nun prüfe, ob der PWRSEL-Header wie im Bild gezeigt bestückt ist. Der mittlere und der untere Jumper sollten gesteckt sein. Dies ist die korrekte Variante für die Versorgung über die Buderus-Steuerung. Wenn du das Modul über USB versorgen willst, musst du den unteren Jumper (blau im Bild) nach oben

versetzen. Orientiere dich dabei an der Beschriftung unter dem Kondensator. Der schwarze Jumper darf nur zum Flashen über die serielle Schnittstelle entfernt werden.

Für die Ethernet-Erweiterung prüfe: J5 ist geschlossen, J4 ist offen, und die Jumper J1 bis J3 sitzen auf den Positionen 2–3.


Figure 2: KM271-WiFi mit Ethernet-Erweiterung

Einbau

Wenn du Ethernet nutzen möchtest, ist jetzt der richtige Zeitpunkt, die Ethernet-Erweiterung aufzustecken.

1. Schalte die Buderus-Steuerung aus
2. Entferne die beiden Schrauben des Gehäuses und hebe es vorsichtig an
3. Biege die über dem KM271-Slot verlaufenden Kabel etwas nach oben, sodass das Modul seitlich eingeschoben werden kann
4. Richte das Modul in den Führungsschienen des KM271 aus und schiebe es nach unten
5. Drücke das Modul vorsichtig in den Steckplatz – es rastet mit einer kleinen Lasche in die rechteckige Öffnung des KM271-Moduls ein (im Bild neben dem Flachsteckverbinder). Wenn du das Modul wieder entfernen möchtest, entriegle die Lasche mit einem Schraubendreher
6. Schließe ggf. weitere Sensoren an: Abgastemperaturfühler, Ölzähler, OneWire usw.
7. Setze das Gehäuse der Buderus-Steuerung wieder auf
8. Schalte die Steuerung wieder ein

Auf dem Display der Buderus-Steuerung sollte nun ein neuer Eintrag ABGAS oder EXHAUST erscheinen. Falls nicht, nutze das Drehrad zur Navigation. Wenn du einen Abgastemperaturfühler angeschlossen hast, wird dessen aktuelle Temperatur angezeigt. Falls nicht, steht dort --- – das ist völlig in Ordnung.

Nun nimm dein Smartphone oder einen PC und suche nach dem WLAN Fallback Hotspot (bei ESPhome, Passwort: Z8zfajgxVvNw) oder ESP-Buderus-KM271 (bei dewennis Firmware). Auf Android fragt das Gerät nach 10–20 Sekunden, ob du verbunden bleiben möchtest (da keine Internetverbindung vorhanden ist) – bestätige mit Ja. Öffne dann den Browser und rufe die Adresse http://192.168.4.1 auf. Manchmal dauert es einige Minuten, bis eine Verbindung aufgebaut oder die Seite geladen ist (vermutlich ein Bug in ESPhome). Bis zu diesem Punkt ist das Vorgehen bei dewennis Firmware identisch – sie reagiert meist nur etwas schneller. Fahre jetzt mit dem passenden Kapitel zu deiner Firmware fort.

## ESPhome-Konfiguration

Du solltest nun die Seite des Fallback-Hotspots sehen:


Figure 3: Fallback-Hotspot-Seite

Wähle dein WLAN und gib das Passwort ein. Wenn du versehentlich das falsche WLAN gewählt hast, ist es später schwierig, wieder Zugriff auf das Board zu bekommen. In diesem Fall musst du das falsche WLAN deaktivieren. Alternativ kannst du das Modul aus der Buderus-Steuerung entfernen, aus dem Empfangsbereich rausgehen und das Modul per USB versorgen (dazu den PWRSEL-Jumper umsetzen). Danach kannst du die Einrichtung erneut starten.
Auf der Seite des Fallback-Hotspots kannst du auch eine neue Firmware flashen – allerdings keine andere Firmware (z. B. nicht die von dewenni).

Nach der Einrichtung sollte das Board in deinem ESPhome-Addon in Home Assistant erscheinen. Du kannst nun die YAML-Konfiguration anpassen oder so lassen, wie sie ist. Wenn eine neue Firmware verfügbar ist
(z. B. durch ein Update des Addons), kann diese in der Regel problemlos eingespielt werden.

Das Gerät und seine Sensoren, Werte usw. findest du in Home Assistant unter:

## Einstellungen → Geräte & Dienste → ESPhome

Weitere Informationen findest du hier: https://github.com/the78mole/ESPhome-KM271-WiFi


## Dewennis MQTT-Konfiguration

Beim ersten Zugriff auf dewennis Web-Oberfläche solltest du zunächst die GPIOs konfigurieren – insbesondere, wenn du die Ethernet-Erweiterung (ETH-Ext) verwenden willst, um das KM271-WiFi mit deinem Heimnetz zu verbinden. Die GPIOs sind wie folgt:

Signal GPIO Pin (J7)

VCC | | J7.2
GND | | J7.10
CLK | 18 | J7.9
MOSI | 23 | J7.7
MISO | 19 | J7.5
CS | 15 | J7.3
INT | 14 | J7.8
RST | 13 | J7.6

Abgesehen von der Ethernet-Konfiguration kannst du alle weiteren Einstellungen auch nach dem Neustart vornehmen.

Danach musst du noch die GPIOs für die Verbindung zur Buderus-Steuerung konfigurieren. Für das KM271-WiFi gibt es eine vordefinierte Option – bitte wähle diese aus. Wenn du andere Hardware anschließen möchtest, findest du hier die detaillierte Beschreibung:

https://bit.ly/4jA7aHu


Für weitere Unterstützung kannst du meinem Matrix-Kanal beitreten: https://matrix.to/#/#molesblog:matrix.org

## Viel Spaß mit deinem Ölbrenner – bis ihn die Wärmepumpe in Rente schickt!

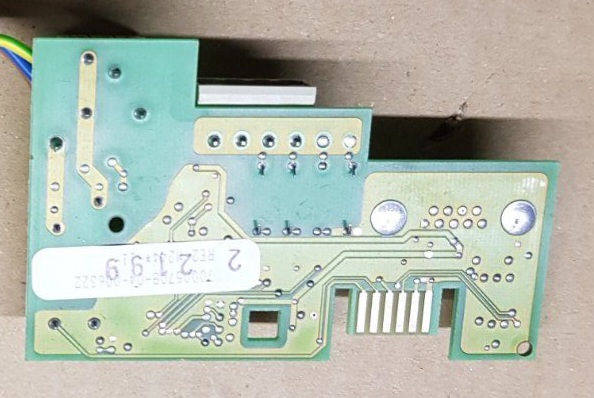
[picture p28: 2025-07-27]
IMG/FM244/FM244 Back.jpeg

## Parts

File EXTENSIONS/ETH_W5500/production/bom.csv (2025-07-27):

Designator | Footprint | Quantity | Value | LCSC Part #
C1, C10, C12, C13, C16, C17, C19, C2, C23, C24, C25, C26, C27, C9 | 0603 | 14 | 100n
C11, C15 | 0805 | 2 | 22u
C14, C30 | 0603 | 2 | 2u2
C18, C3 | 0603 | 2 | 10n
C20, C21 | 0603 | 2 | 6n8
C22 | 0603 | 1 | 22n
C28, C31, C32, C34 | 0603 | 4 | 4n7
C33 | 1206 | 1 | 1n
C4 | 0805 | 1 | 4u7
C7, C8 | 0603 | 2 | 18p
D10 | 0603 | 1 | green
D9 | 0603 | 1 | red
J1 | WE_PinSocket_TH_2x05_P2.54mm_Vertical_SMD | 1 | EXT
J2 | WE-MJ-634008137521 | 1 | WE-634008137521
J3 | WE-MM-690367290876 | 1 | MM-690367290876
JP1 | SolderJumper-3_P1.3mm_Open_RoundedPad1.0x1.5mm_NumberLabels | 1 | PM0
JP2 | SolderJumper-3_P1.3mm_Open_RoundedPad1.0x1.5mm_NumberLabels | 1 | PM1
JP3 | SolderJumper-3_P1.3mm_Open_RoundedPad1.0x1.5mm_NumberLabels | 1 | PM2
L2 | 0805 | 1 | FB
R1, R2 | 0603 | 2 | 0
R10, R9 | 0603 | 2 | 680
R11, R12 | 0603 | 2 | 82
R13, R14, R20, R21 | 0603 | 4 | 49R9
R15 | 0603 | 1 | 10
R16, R17 | 0603 | 2 | 75
R18, R19 | 0603 | 2 | 150
R22, R23 | 0603 | 2 | 330
R3 | 0603 | 1 | 1M
R4 | 0603 | 1 | 12K4
R5, R6, R7, R8 | 0603 | 4 | 33
TR1 | Transformer_Ethernet_Wuerth_749013011A | 1 | Wuerth_7490100111A
U2 | SOT-223-3_TabPin2 | 1 | AP1117-33
U3 | LQFP-48_7x7mm_P0.5mm | 1 | W5500
Y1 | Crystal_SMD_HC49-SD | 1 | 25M

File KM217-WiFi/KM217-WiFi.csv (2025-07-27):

Source: | C:\GIT\Hardware\Buderus-KM217-Clone\KM217-WiFi\KM217-WiFi.kicad_sch
Date: | 2025-03-10T00:09:37+0100
Tool: | Eeschema 9.0.0
Generator: | C:\Program Files\KiCad\9.0\bin\scripting\plugins/bom_csv_grouped_by_value_with_fp.py
Component Count: | 121
Ref | Qnty | Value | Cmp name | Footprint | Description | Vendor | DNP
C1, C3, C4, C6, C9, C10, C11, C15, C16, C17, C19, C20, C21, C22, C23, C24 | 16 | 100n | C_Small | Capacitor_SMD:C_0603_1608Metric_Pad1.08x0.95mm_HandSolder | Unpolarized capacitor, small symbol
C2, C5, C14 | 3 | 2u2 | C_Small | Capacitor_SMD:C_0603_1608Metric_Pad1.08x0.95mm_HandSolder | Unpolarized capacitor, small symbol
C7, C8 | 2 | 100u/16V | C_Polarized_Small | Capacitor_SMD:CP_Elec_6.3x5.4_Nichicon | Polarized capacitor, small symbol
C12 | 1 | 33n | C_Small | Capacitor_SMD:C_0603_1608Metric_Pad1.08x0.95mm_HandSolder | Unpolarized capacitor, small symbol
C13 | 1 | 22u/10V | C_Polarized_Small | Capacitor_SMD:C_1812_4532Metric_Pad1.57x3.40mm_HandSolder | Polarized capacitor, small symbol
C18 | 1 | 4p7 | C_Small | Capacitor_SMD:C_0603_1608Metric_Pad1.08x0.95mm_HandSolder | Unpolarized capacitor, small symbol
D1, D2 | 2 | LED green | LED | LED_SMD:LED_0603_1608Metric_Pad1.05x0.95mm_HandSolder | Light emitting diode
D3 | 1 | LED yellow | LED | LED_SMD:LED_0603_1608Metric_Pad1.05x0.95mm_HandSolder | Light emitting diode
D4 | 1 | LED red | LED | LED_SMD:LED_0603_1608Metric_Pad1.05x0.95mm_HandSolder | Light emitting diode
D5 | 1 | BZX84C5V1 | D_Zener | Diode_SMD:D_SOT-23_ANK | Zener diode |  | DNP
H1 | 1 | MountingHole | MountingHole | MountingHole:MountingHole_3.2mm_M3_DIN965 | Mounting Hole without connection
J1 | 1 | KM271-CON | Conn_02x06_Odd_Even | the78mole:LM2107_ComModuleCon | Generic connector, double row, 02x06, odd/even pin numbering scheme (row 1 odd numbers, row 2 even numbers), script generated (kicad-library-utils/schlib/autogen/connector/)
J2 | 1 | USB_B_Mini | USB_B_Mini | the78mole:USB_Mini-B_Wuerth_65100516121_Horizontal | USB Mini Type B connector
J3 | 1 | VSEL | Conn_02x03_Odd_Even | Connector_PinHeader_2.54mm:PinHeader_2x03_P2.54mm_Vertical_SMD | Generic connector, double row, 02x03, odd/even pin numbering scheme (row 1 odd numbers, row 2 even numbers), script generated (kicad-library-utils/schlib/autogen/connector/)
J4 | 1 | DEBUG | Conn_01x06 | Connector_PinHeader_2.54mm:PinHeader_2x03_P2.54mm_Horizontal | Generic connector, single row, 01x06, script generated (kicad-library-utils/schlib/autogen/connector/) |  | DNP
J5 | 1 | ATS | Conn_01x02 | Connector_Phoenix_MSTB:PhoenixContact_MSTBA_2,5_2-G-5,08_1x02_P5.08mm_Horizontal | Generic connector, single row, 01x02, script generated (kicad-library-utils/schlib/autogen/connector/) |  | DNP
J6 | 1 | TSENS | Conn_01x08 | the78mole:WAGO 2086-1208 | Generic connector, single row, 01x08, script generated (kicad-library-utils/schlib/autogen/connector/) |  | DNP
J7 | 1 | EXT | Conn_02x05_Odd_Even | Connector_PinHeader_2.54mm:PinHeader_2x05_P2.54mm_Vertical_SMD | Generic connector, double row, 02x05, odd/even pin numbering scheme (row 1 odd numbers, row 2 even numbers), script generated (kicad-library-utils/schlib/autogen/connector/)
J8 | 1 | ATS_mate | Screw_Terminal_01x02 |  | Generic screw terminal, single row, 01x02, script generated (kicad-library-utils/schlib/autogen/connector/) |  | DNP
R1, R3, R19, R20, R21, R22 | 6 | 220 | R_Small | Resistor_SMD:R_0603_1608Metric_Pad0.98x0.95mm_HandSolder | Resistor, small symbol
R2, R27, R29, R32 | 4 | 10K | R_Small | Resistor_SMD:R_0603_1608Metric_Pad0.98x0.95mm_HandSolder | Resistor, small symbol
R4, R30, R61, R62, R63 | 5 | 4K7 | R_Small | Resistor_SMD:R_0603_1608Metric_Pad0.98x0.95mm_HandSolder | Resistor, small symbol
R5, R11 | 2 | 100K | R_Small | Resistor_SMD:R_0603_1608Metric_Pad0.98x0.95mm_HandSolder | Resistor, small symbol
R6 | 1 | 10 | R_Small | Resistor_SMD:R_0603_1608Metric_Pad0.98x0.95mm_HandSolder | Resistor, small symbol
R7, R8, R33, R34, R35, R36, R37, R38, R39, R40, R57, R59, R64, R65, R66 | 15 | 0 | R_Small | Resistor_SMD:R_0603_1608Metric_Pad0.98x0.95mm_HandSolder | Resistor, small symbol
R9 | 1 | 330 | R_Small | Resistor_SMD:R_0603_1608Metric_Pad0.98x0.95mm_HandSolder | Resistor, small symbol
R10, R13, R14, R15, R18, R31, R41, R42, R43, R44, R52, R53, R58, R67, R68 | 15 | np | R_Small | Resistor_SMD:R_0603_1608Metric_Pad0.98x0.95mm_HandSolder | Resistor, small symbol |  | DNP
R12 | 1 | 47K | R_Small | Resistor_SMD:R_0603_1608Metric_Pad0.98x0.95mm_HandSolder | Resistor, small symbol
R16, R49, R50, R51 | 4 | 1K | R_Small | Resistor_SMD:R_0603_1608Metric_Pad0.98x0.95mm_HandSolder | Resistor, small symbol
R17 | 1 | 3K3 | R_Small | Resistor_SMD:R_0603_1608Metric_Pad0.98x0.95mm_HandSolder | Resistor, small symbol
R23, R24, R25, R26 | 4 | 680 | R_Small | Resistor_SMD:R_0603_1608Metric_Pad0.98x0.95mm_HandSolder | Resistor, small symbol
R28 | 1 | 1M | R_Small | Resistor_SMD:R_0603_1608Metric_Pad0.98x0.95mm_HandSolder | Resistor, small symbol
R45, R46, R47, R48, R54, R55, R56, R60 | 8 | 22 | R_Small | Resistor_SMD:R_0603_1608Metric_Pad0.98x0.95mm_HandSolder | Resistor, small symbol
SW1 | 1 | USER2 | SW_Push | Button_Switch_SMD:SW_SPST_B3SL-1002P | Push button switch, generic, two pins |  | DNP
SW2 | 1 | USER1 | SW_Push | Button_Switch_SMD:SW_SPST_B3SL-1002P | Push button switch, generic, two pins |  | DNP
SW3 | 1 | BOOT | SW_Push | Button_Switch_SMD:SW_SPST_B3SL-1002P | Push button switch, generic, two pins
SW4 | 1 | RESET | SW_Push | Button_Switch_SMD:SW_SPST_B3SL-1002P | Push button switch, generic, two pins
TP1, TP2, TP3, TP4 | 4 | TestPoint | TestPoint | TestPoint:TestPoint_Pad_D2.0mm | test point
U1 | 1 | ESP32-WROOM-32D | ESP32-WROOM-32D | RF_Module:ESP32-WROOM-32 | RF Module, ESP32-D0WD SoC, Wi-Fi 802.11b/g/n, Bluetooth, BLE, 32-bit, 2.7-3.6V, onboard antenna, SMD
U2 | 1 | AZ1117IH-3.3TRG1 | AP1117-33 | Package_TO_SOT_SMD:SOT-223-3_TabPin2 | 1A Low Dropout regulator, positive, 3.3V fixed output, SOT-223
U3 | 1 | 24LC1025 | 24LC1025 | Package_SO:SO-8_5.3x6.2mm_P1.27mm | I2C Serial EEPROM, 1024Kb, DIP-8/SOIC-8/TSSOP-8/DFN-8 |  | DNP
U4, U5 | 2 | SN74LV1T34DBV | SN74LV1T34DBV | Package_TO_SOT_SMD:SOT-23-5 | Single Power Supply, Single Buffer GATE, CMOS Logic, Level Shifter, SOT-23-5
U6 | 1 | PCA9306DC1 | PCA9306DC1 | Package_SO:VSSOP-8_2.3x2mm_P0.5mm | Dual bidirectional I2C Bus and SMBus voltage level translator, VSSOP-8 |  | DNP
U7 | 1 | DS2484 | DS2484 | Package_TO_SOT_SMD:SOT-23-6_Handsoldering |  |  | DNP

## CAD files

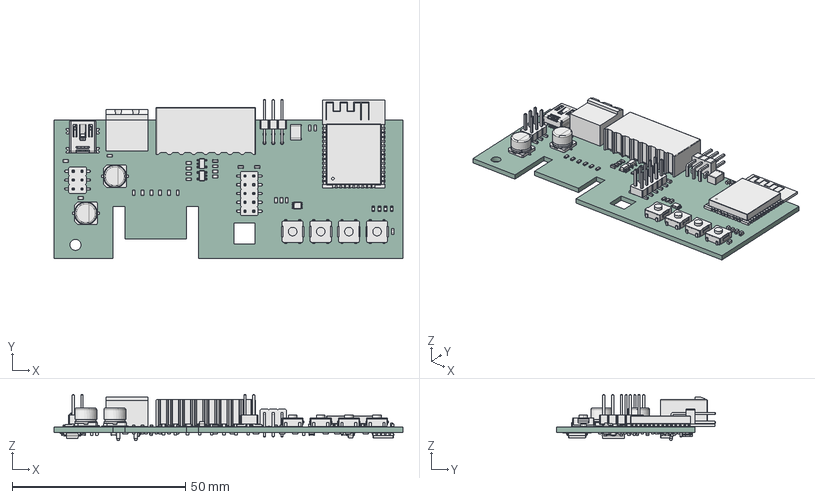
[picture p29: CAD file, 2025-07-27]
EXTENSIONS/3d-helper.FCStd
100.8 x 46.0 x 13.3 mm
_autosave-KM217-WiFi PCB

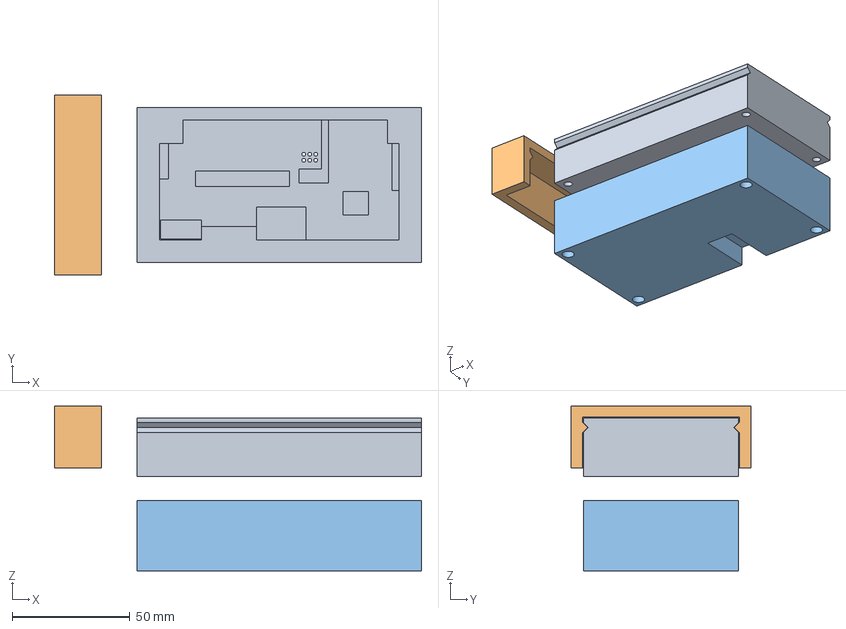
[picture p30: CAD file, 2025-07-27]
MECH/Pogo-Frame.FCStd
155.8 x 76.5 x 70.0 mm
Körper
Körper001
Körper002

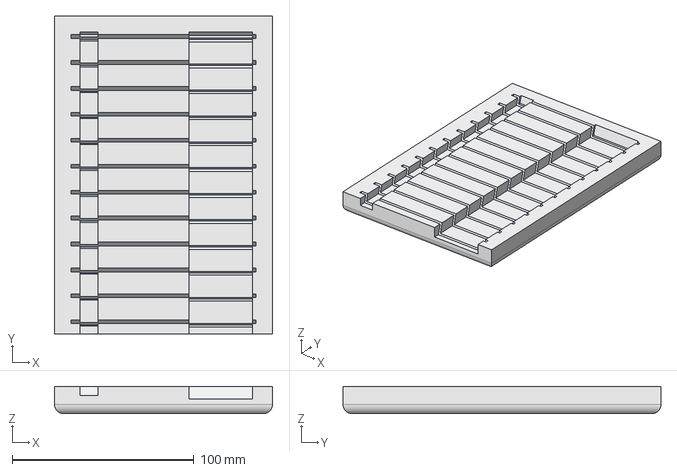
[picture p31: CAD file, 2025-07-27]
MECH/Holder.FCStd
120.0 x 175.0 x 15.0 mm

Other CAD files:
MECH/Holder.stl
MECH/Pogo-Frame.stl

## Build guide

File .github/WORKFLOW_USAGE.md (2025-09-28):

# GitHub Actions Workflow Usage

## 📋 Overview

This repository contains a GitHub Actions workflow for automated KiCad hardware builds and documentation generation.

## 🔧 Workflow: `pr-check.yml`

### What it does:
- **Hardware Build & Export**: Exports KiCad files to production-ready formats
- **Documentation Build**: Validates and processes documentation files
- **PR Summary**: Generates automated PR comments with build results

### Jobs:

#### 1. 🔧 Hardware Build & Export
- Validates KiCad project files
- Exports Gerber files for PCB manufacturing
- Generates drill files
- Creates PDF documentation (schematics and PCB layouts)
- Exports SVG assembly diagrams
- Generates 3D STEP models
- Creates production summary
- Uploads all artifacts

#### 2. 📚 Documentation Build
- Validates Markdown documentation
- Builds AsciiDoc files (if present)
- Generates LaTeX PDFs (if present)
- Checks for broken links
- Creates documentation statistics
- Uploads documentation artifacts

#### 3. 📋 PR Summary (PR only)
- Downloads artifacts from previous jobs
- Generates comprehensive PR summary
- Comments results on Pull Request

## 🚀 Usage

### GitHub Actions (Automatic)
The workflow runs automatically on:
- Pull Requests to `main` or `develop` branches
- Pushes to `main` branch
- Changes to:
  - `KM217-WiFi/**` (hardware files)
  - `DOC/**` (documentation)
  - `.github/workflows/pr-check.yml` (workflow itself)

### Local Testing with `act`

#### Prerequisites
```bash
# Install act (GitHub Actions runner)
# macOS
brew install act

# Linux
curl https://raw.githubusercontent.com/nektos/act/master/install.sh | sudo bash

# Or download from: https://github.com/nektos/act/releases
```

#### Run Local Tests
```bash
# Test hardware build only
act -j hardware-build --artifact-server-path /tmp/artifacts

# Test documentation build only
act -j documentation-build --artifact-server-path /tmp/artifacts

# Test complete workflow (excluding PR comments)
act --artifact-server-path /tmp/artifacts

# Use specific Docker platform (if needed)
act -j hardware-build --artifact-server-path /tmp/artifacts --container-architecture linux/amd64
```

#### Local Artifacts
When using `act`, artifacts are stored locally:
- **Location**: `/tmp/artifacts/[run-id]/[artifact-name]/`
- **Hardware exports**: `/tmp/artifacts/*/km217-wifi-hardware-exports/`
- **Documentation**: `/tmp/artifacts/*/km217-wifi-documentation/`

#### Extract Artifacts from Container
```bash
# Copy artifacts from act container to host
docker cp $(docker ps -lq):/tmp/artifacts/ ./local-artifacts/
```

## 📦 Generated Artifacts

### Hardware Exports (`km217-wifi-hardware-exports`)
- **Gerber Files**: `Export/Gerbers/` - PCB manufacturing files
- **Drill Files**: `Export/Drill/` - Drill hole information
- **PDFs**: `Export/PDF/` - Schematics and PCB layout documentation
- **Images**: `Export/Images/` - SVG assembly diagrams
- **3D Models**: `Export/3D/` - STEP files for 3D visualization
- **Summary**: `Export/PRODUCTION_SUMMARY.md` - Complete file overview

### Documentation (`km217-wifi-documentation`)
- All files from `DOC/` directory
- Generated HTML/PDF files (if applicable)
- Documentation statistics

## 🔧 Customization

### Modify KiCad Export Settings
Edit the workflow file `.github/workflows/pr-check.yml`:

```yaml
# Example: Add more PCB layers
--layers "F.Cu,B.Cu,In1.Cu,F.Paste,B.Paste,F.Silkscreen,B.Silkscreen,F.Mask,B.Mask,Edge.Cuts"

# Example: Change precision
--precision 5  # or 6
```

### Add Custom Validation
Add custom steps in the workflow:

```yaml
- name: 🔍 Custom Validation
  run: |
    echo "Running custom validation..."
    # Your custom validation logic here
```

## 🐛 Troubleshooting

### Common Issues

1. **Missing 3D Models**: The STEP export shows warnings about missing 3D models. This is normal and doesn't affect the PCB manufacturing files.

2. **ImageMagick not available**: PNG conversion is skipped. SVG files are still generated.

3. **act fails with permissions**: Make sure Docker is running and you have permissions:
   ```bash
   sudo usermod -aG docker $USER
   # Log out and back in
   ```

4. **Workflow fails on syntax**: Check bash syntax in workflow scripts, especially:
   - Array definitions
   - String substitutions
   - EOF delimiters

### Debug Tips

1. **Enable act debug mode**:
   ```bash
   act -j hardware-build --artifact-server-path /tmp/artifacts --verbose
   ```

2. **Check generated files locally**:
   ```bash
   ls -la /tmp/artifacts/*/km217-wifi-hardware-exports/
   unzip -l /tmp/artifacts/*/km217-wifi-hardware-exports/*.zip
   ```

3. **Validate KiCad CLI commands manually**:
   ```bash
   # In KiCad project directory
   kicad-cli sch export pdf --help
   kicad-cli pcb export gerbers --help
   ```

## 📚 References

- [GitHub Actions Documentation](https://docs.github.com/en/actions)
- [act - Local GitHub Actions](https://github.com/nektos/act)
- [KiCad CLI Documentation](https://docs.kicad.org/master/en/cli/cli.html)
- [KiCad Docker Image](https://github.com/the78mole/docker-images)

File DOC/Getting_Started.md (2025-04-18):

---
title: "KM271-WiFi Quick Start Guide"
author: "Daniel (the78mole) Glaser"
---

# KM271-WiFi Quick Start

This is a short guide for commissioning the KM271-WiFi module.

KM271-WiFi mostly assembled

## Prerequisites

First, check if everything is present as ordered (from left to right):

- **J5** is the connector for the exhaust temperature sensor (the counterpart was included in the package; colors may vary: black or green)
- **J6** is the connector for sensor lines
- **J4** is the debug interface for programming via a serial connection

Depending on your order and selected options, some connectors may not be populated. The Ethernet extension in the second image is a separate module, also available in my Tindie store.

KM271-WiFi with Ethernet Extension

Now **check if the PWRSEL header** is configured as shown in the image. The middle and bottom jumpers should be in place. This is the correct setup for **powering via the Buderus control unit**. If you want to **power the module via USB**, you need to move the bottom jumper (blue in the image) to the top. Use the label under the capacitor as orientation. The black jumper must only be removed when flashing via the serial interface.

For the Ethernet extension, check: J5 is closed, J4 is open, and jumpers J1 to J3 are set to positions 2–3.

## Installation

If you plan to use Ethernet, now is the right time to attach the Ethernet extension.

1. Power off the Buderus control unit  
2. Remove the two screws of the housing and lift it carefully  
3. Slightly bend the cables above the KM271 slot upward so the module can be inserted from the side  
4. Align the module with the guide rails of the KM271 and slide it down  
5. Gently press the module into the slot – it clicks into place with a small tab in the rectangular opening of the KM271 module (shown next to the flat connector in the picture). To remove it again, release the tab with a screwdriver  
6. Connect additional sensors if needed: exhaust temperature probe, oil meter, OneWire, etc.  
7. Reattach the housing of the Buderus control unit  
8. Power the unit back on

The Buderus control unit's display should now show a new entry `ABGAS` or `EXHAUST`. If not, use the rotary knob to navigate. If an exhaust temperature sensor is connected, its current temperature will be shown. If not, it will display `---` – which is perfectly fine.

Now take your smartphone or PC and look for the Wi-Fi network `Fallback Hotspot` (for ESPhome, passphrase: `Z8zfajgxVvNw`) or `ESP-Buderus-KM271` (for dewennis firmware). On Android, the device may ask after 10–20 seconds whether you want to stay connected (since there’s no internet) – confirm with `Yes`. Then open your browser and visit http://192.168.4.1. Sometimes it takes a few minutes to establish the connection or load the page (probably a bug in ESPhome). Up to this point, the steps are the same for dewennis firmware – it's usually just a bit faster. Continue with the appropriate chapter for your firmware.

### ESPhome Configuration

You should now see the fallback hotspot page:

Fallback Hotspot Page

Select your Wi-Fi and enter the password. If you accidentally choose the wrong network, it can be difficult to regain access to the board. In that case, you need to disable the wrong Wi-Fi. Alternatively, you can remove the module from the Buderus unit, move out of WiFi range and power it via USB (set the PWRSEL jumper accordingly). Then you can restart the setup process.

You can also flash a new firmware on the fallback hotspot page – but **not a different firmware** (e.g., the one by dewenni).

After setup, the board should appear in your ESPhome add-on in Home Assistant. You can now adjust the YAML configuration or leave it as is. If a new firmware version becomes available (e.g., via an update to the add-on), it can usually be flashed without issue.

You’ll find the device and its sensors, values, etc., in Home Assistant under:  
**Settings → Devices & Services → ESPhome**

More information:  
https://github.com/the78mole/ESPhome-KM271-WiFi

QR (https://github.com/the78mole/ESPhome-KM271-WiFi)

### Dewennis MQTT Configuration

On first access to the dewennis web interface, you should configure the GPIOs – especially if you plan to use the Ethernet extension (ETH-Ext) to connect the KM271-WiFi to your home network. The GPIOs are as follows:

| Signal | GPIO  | Pin (J7) |
|---|---|---|
| VCC | | J7.2 |
| GND | | J7.10 |
| CLK | 18 | J7.9 |
| MOSI | 23 | J7.7 |
| MISO | 19 | J7.5 |
| CS | 15 | J7.3 |
| INT | 14 | J7.8 |
| RST | 13 | J7.6 |

Apart from the Ethernet configuration, all other settings can be made after a restart.

Next, you need to configure the GPIOs for communication with the Buderus control unit. A predefined option exists for KM271-WiFi – please select it. If you want to connect different hardware, a detailed description is available here:

https://bit.ly/4jA7aHu

QR (https://bit.ly/4jA7aHu)

---

For additional support, you can join my Matrix channel:  
https://matrix.to/#/#molesblog:matrix.org

---

**Enjoy your oil burner – until the heat pump sends it into retirement!**

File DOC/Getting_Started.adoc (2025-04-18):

= KM271-WiFi Quick Start Guide
Daniel (the78mole) Glaser
:doctype: article
:lang: en
:encoding: utf-8
:icons: font
:source-highlighter: pygments
:toc: macro
:toclevels: 2
:sectnums:
:imagesdir: ../IMG
:pdf-page-size: A5
:pdf-font-size: 9

== KM271-WiFi Quick Start

This is a short guide for commissioning the KM271-WiFi module.

KM271-WiFi mostly assembled

== Prerequisites

First, check if everything is present as ordered (from left to right):

* *J5* is the connector for the exhaust temperature sensor (the counterpart was included in the package; wire colors may vary: black or green)
* *J6* is the connector for sensor lines
* *J4* is the debug interface for programming via a serial connection

Depending on your order and selected options, some connectors may not be populated. The Ethernet extension in the second image is a separate module, also available in my Tindie store.

KM271-WiFi with Ethernet Extension

Now *check if the PWRSEL header* is configured as shown in the image. The middle and bottom jumpers should be in place. This is the correct setup for *powering via the Buderus control unit*. If you want to *power the module via USB*, you need to move the bottom jumper (blue in the image) to the top. Use the label under the capacitor as orientation. The black jumper must only be removed when flashing via the serial interface.

For the Ethernet extension, check: J5 is closed, J4 is open, and jumpers J1 to J3 are set to positions 2–3.

== Installation

If you plan to use Ethernet, now is the right time to attach the Ethernet extension.

1. Power off the Buderus control unit
2. Remove the two screws of the housing and lift it carefully
3. Slightly bend the cables above the KM271 slot upward so the module can be inserted from the side
4. Align the module with the guide rails of the KM271 and slide it down
5. Gently press the module into the slot – it clicks into place with a small tab in the rectangular opening of the KM271 module (shown next to the flat connector in the picture). To remove it again, release the tab with a screwdriver
6. Connect additional sensors if needed: exhaust temperature probe, oil meter, OneWire, etc.
7. Reattach the housing of the Buderus control unit
8. Power the unit back on

The Buderus control unit's display should now show a new entry `ABGAS` or `EXHAUST`. If not, use the rotary knob to navigate. If an exhaust temperature sensor is connected, its current temperature will be shown. If not, it will display `---` – which is perfectly fine.

Now take your smartphone or PC and look for the Wi-Fi network `Fallback Hotspot` (for ESPhome) or `ESP-Buderus-KM271` (for dewennis firmware). On Android, the device may ask after 10–20 seconds whether you want to stay connected (since there’s no internet) – confirm with `Yes`. Then open your browser and visit http://192.168.4.1. Sometimes it takes a few minutes to establish the connection or load the page (probably a bug in ESPhome). Up to this point, the steps are the same for dewennis firmware – it's usually just a bit faster. Continue with the appropriate chapter for your firmware.

=== ESPhome Configuration

You should now see the fallback hotspot page:

Fallback Hotspot Page

Select your Wi-Fi and enter the password. If you accidentally choose the wrong network, it can be difficult to regain access to the board. In that case, you need to disable the wrong Wi-Fi or move the module out of its range. Alternatively, you can remove the module from the Buderus unit, power it via USB, and move out of Wi-Fi range (set the PWRSEL jumper accordingly). Then you can restart the setup process.

You can also flash a new firmware on the fallback hotspot page – but *not a different firmware* (e.g., the one by dewenni).

After setup, the board should appear in your ESPhome add-on in Home Assistant. You can now adjust the YAML configuration or leave it as is. If a new firmware version becomes available (e.g., via an update to the add-on), it can usually be flashed without issue.

You’ll find the device and its sensors, values, etc., in Home Assistant under:  
*Settings → Devices & Services → ESPhome*

More information:  
https://github.com/the78mole/ESPhome-KM271-WiFi

image::https://api.qrserver.com/v1/create-qr-code/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[QR, link=https://github.com/the78mole/ESPhome-KM271-WiFi]

=== Dewennis MQTT Configuration

On first access to the dewennis web interface, you should configure the GPIOs – especially if you plan to use the Ethernet extension (ETH-Ext) to connect the KM271-WiFi to your home network. The GPIOs are as follows:

[cols="1,1,1", options="header,frame=all,grid=all"]
|===
| Signal | GPIO | Pin (J7)
| VCC    |      | J7.2
| GND    |      | J7.10
| CLK    | 18   | J7.9
| MOSI   | 23   | J7.7
| MISO   | 19   | J7.5
| CS     | 15   | J7.3
| INT    | 14   | J7.8
| RST    | 13   | J7.6
|===

Apart from the Ethernet configuration, all other settings can be made after a restart.

Next, you need to configure the GPIOs for communication with the Buderus control unit. A predefined option exists for KM271-WiFi – please select it. If you want to connect different hardware, a detailed description is available here:

https://bit.ly/4jA7aHu

image::https://api.qrserver.com/v1/create-qr-code/?data=https%3A%2F%2Fbit.ly%2F4jA7aHu&size=150x150[QR, link=https://bit.ly/4jA7aHu]

'''

For additional support, you can join my Matrix channel:  
https://matrix.to/#/#molesblog:matrix.org

'''

*Enjoy your oil burner – until the heat pump sends it into retirement!*

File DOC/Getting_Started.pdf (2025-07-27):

KM271-WiFi Getting Started Guide KM217 WiFi Getting Started
This is a quick manual, how to install the KM271-WiFi module.
Prerequisites
First, check if everything is as ordered (from left to right):
- J5 is the exhaust temperature sensor connector (mating part was in the package, colors may vary: black or green)
- J6 is the sensor header connector
- J4 is the debug header for programming over serial wire
Depending on your order and options, you will find some connectors not populated. The Ethernet extension in the second image is a separate module, also available in my Tindie store.

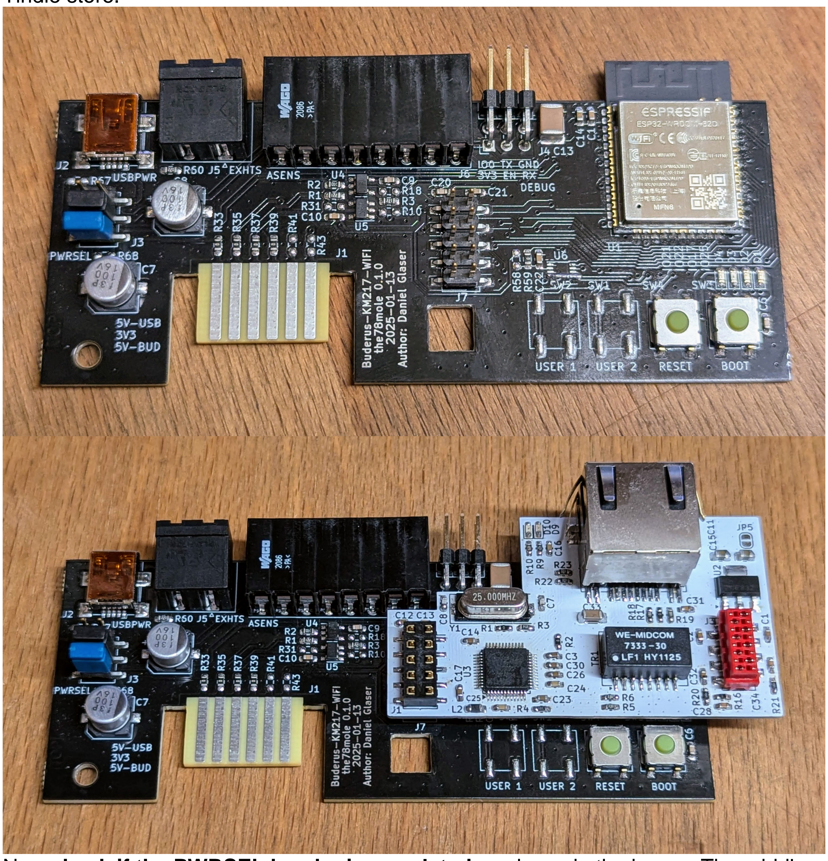
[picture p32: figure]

Now check if the PWRSEL header is populated as shown in the image. The middle and the lower jumper shall be set. This is the right variant for supply from Buderus control unit. If you want to supply via USB, you need to move the lower Jumper (blue in the image) to the top position. Take the text below the capacitor as a reference. The black jumper shall only be removed for flashing through serial.
For the Ethernet extension, check if the Jumpers J5 is closed, J4 is open and J1 to J3 are placed on pads 2-3.
Installation
Now would be the right time, to add the ethernet extension to the KM271-WiFi if you want to use ethernet.
1. Switch off the Buderus control unit
2. Remove the two screws of the Buderus case and lift it up
3. Try to bend the wires going over the slot of the KM271 a bit up, just enough to slide the KM271 in from the side
4. Align the module in the slots for the KM271 and slide it downwards
5. Push the module gently into its socket, there will be a latch snapping into the rectangular hole of the KM271-module (in the image right beside the blade connector). If you want to remove the module again, you should unlock the latch with the help of a screwdriver
6. Connect additional sensors to the board: Exhaust sensor, oil counter, one-wire,…
7. Close the case of the Buderus control unit again
8. Power it on again
In the display of the Buderus control unit, you should see a new information ABGAS or EXHAUST. If not, try finding it with the scroll wheel. If you added an exhaust sensor, you can read its current temperature. If you don’t have an exhaust temperature sensor, you will read ---. That is totally fine.
Now take your smartphone or a PC and search for WiFi Fallback Hotspot (ESPhome) or ESP-Buderus-KM271 (dewenni’s). On Android, after 10–20 seconds, it asks you, if you are sure you want to stay connected (because of missing internet access). Choose yes. Now head over to your browser and go to http://192.168.4.1. Be patient, it sometimes takes some minutes to be able to connect to the wifi or access the page (seems to be a bug in ESPhome). Up to here, it is the same procedure with dewenni’s firmware (the latter just works a bit smoother and more instant). Process with the chapter for your firmware.
ESPhome setup
You will see the page of the fallback hotspot:

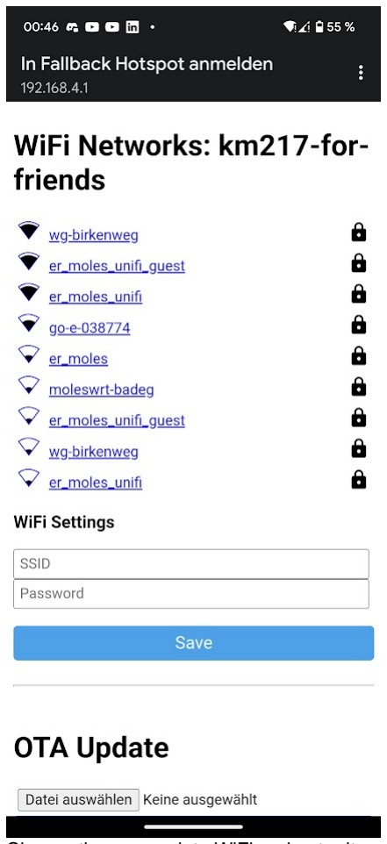
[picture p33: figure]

Choose the appropriate WiFi and enter its passphrase. If you selected the wrong WiFi, it is hard to gain access to the board again… You need to switch off the wrong WiFi or move the module out of the reach. For that purpose, you can take the module out of the Buderus and supply it via USB (you need to move the PWRSEL jumper). Then you can start the procedure again.
On the fallback hotspot page, you can also flash a new firmware version, but you can not use a different firmware (e.g. switch to dewenni’s).
After this procedure, the board should show up in your ESPhome add-on of your smart home. You can now change the yaml config for this device or keep it as is. If there is an update of the firmware available (because ESPhome addon received an update) it should be safe to execute.
You can also find the device and its sensors, numbers,…¬ in Home Assistant ¬ Settings ¬ Devices and Integrations ¬ ESPhome.

Further information: https://github.com/the78mole/ESPhome-KM271-WiFi

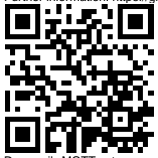
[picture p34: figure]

Dewenni’s MQTT setup
When first accessing dewenni’s WebUI, you should first setup the GPIOs, especially if you want to use Ethernet with the ETH-Ext module to connect your KM271-WiFi to your home network. These GPIOs are:
Signal | GPIO | Pin (J7)
VCC | | J7.2
GND | | J7.10
CLK | 18 | J7.9
MOSI | 23 | J7.7
MISO | 19 | J7.5
CS | 15 | J7.3
INT | 14 | J7.8
RST | 13 | J7.6
Beside the ethernet config, all settings can be done after applying the settings with reboot.
Then you also need to set at least the GPIOs for the interface to the Buderus control unit. For the KM271-WiFi, there is a dedicated option. Please select it. If you want to connect different hardware, please refer to the detailed description: https://bit.ly/4jA7aHu

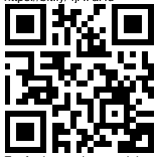
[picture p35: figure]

For further assistance, join my Matrix channel: https://matrix.to/#/#molesblog:matrix.org Have some fun with your oil burner, until it gets retired by a heat pump :-)

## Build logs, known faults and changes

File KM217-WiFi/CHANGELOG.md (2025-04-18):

= Changelog

== 0.0.8 -> 0.1.0

    - TSENS changed CH7 input circuitry to oil counter compatible configuration
	  * R52: 1K -> np (remove pull-up)
	  * R16: np -> 1K (add pull-down)
	  * R9 : 0R -> 300R  (make it 5V compatible)

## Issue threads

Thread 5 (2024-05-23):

Schematic question

blacksheepinc, 2024-05-23:
Hello

I'm making my simple wiring with an ESP32 and logic level converter only for communication with the Buderus,
I've tried your ESPHOME and diwanni's firmware (https://github.com/dewenni/ESP_Buderus_KM271), however I cannot get it communicate.
I've also tried a simple 5V FTDI, and an oscilloscope to see the TX line, but nothing is coming.

I've recently discovered on your Blog, that a 10K resistor is required between Pin4 and Pin8. But still no sign of communication, even switching rx/tx wires.

Is this part of the schematic is mandatory to the module to be working?

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

Thanks!
Mark

the78mole, 2024-05-26:
Hi Mark,

sorry for the late reply, I had a week of vacations with family and was almost 100% offline.

The part is not mandatory, only the 10K (R32) for the Buderus to activate the UART comms.

Sorry for asking silly questions, but do you have one of my boards or do you want to connect the buderus with your own wiring? That's totally OK for me, but it would be easier for me, to identify your problem...

Regards,
Daniel

blacksheepinc, 2024-05-26:
Hello Daniel,

No worries, hope you had nice vacation!

I'm using a simple esp32 devboard, I've replaced the 12pin header from the buderus bus panel with a basic pin header. I'm using dupont cables.

Somehow I cannot get any sign of serial traffic. I'll double check my wiring tomorrow.
Does the buderus automatically broadcast any periodical data on TX if it successfully recognized the board?

Thank you for your great writeup on your blog, very informative!
Mark

the78mole, 2024-05-27:
Hi Mark,

The Logamatic is not sending anything without the 10K detection resistor R32 between P4 and P8.

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

If this resistor is connected, the Logamatic only sends updates of values, if they have changed (e.g. the outside temperature changed from 11 to 12 °C). Only if you request the full dataset, then it will push all values to the bus.

But there is still a protocol underlying all these communications, called "Prozedur 3964R", which is somewhat of a ping pong you need to play with the controller of the Logamatic. You can find some description [here](https://de.wikipedia.org/wiki/3964R). The original document from Buderus is [here](https://buderus-de-de.boschtt-documents.com/download/pdf/file/63011376.pdf).

In the screenshot of the serial terminal in the ["How to Debug a Remote Serial Connection"-Section](https://the78mole.de/reverse-engineering-the-buderus-km217/#How_To_Debug_A_remote_Serial_Connection_Easily) of my blogpost, you can see already some 3964R-stuff happening.

As far as I remember, there is also nothing happening on the serial line, when you do not tickle it to send something.

Have fun :-)

Regards,
Daniel

blacksheepinc, 2024-05-29:
Thanks for the great support, somehow I've managed to make it work. Still I did not change anything, just I was fiddling and bamm it works since then.
Now I'm getting familiar with the options I've got now.

Thanks again!

Closed 2024-11-29.

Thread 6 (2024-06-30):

Board 0.0.8 bootet nur mit Reset-Taste an USB und Logamatic

mutex1980, 2024-06-30:
Hallo,

was kann ich tun, wenn das Board (Rev. 0.0.8) am USB nur in den seltensten Fällen und in der Logamatic nie beim Power-On booted? Ich muss immer die Reset Taste drücken ab dann funktioniert Alles einwandfrei.

Danke und Gruß,
Mirko

mutex1980, 2024-06-30:
Ok schein ein Duplikat zu sein:

https://github.com/dewenni/ESP_Buderus_KM271/issues/99

the78mole, 2024-06-30:
Hallo Mirko,

irgendwie verstehe ich Deinen Satz nicht ganz... Da kommt zwei Mal "am USB" vor... Ich nehme einfach mal an, eines davon meint: In der Buderus. Ich vermute, Du setzt auch den Power Jumper jeweils richtig auf USB oder Buderus, oder?

Grüße,
Daniel

mutex1980, 2024-06-30:
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

Ja Du hast Recht, sorry, ich habe den originalen Satz korrigiert. Es sind beide Fälle gemeint USB und Logamatic.

the78mole, 2024-06-30:
Hallo Mirko,

Naja, man kann das Board ja auch über USB versorgen, wenn es in der Buderus steckt, dann muss der Jumper auch pben auf USB stecken, sonst kann man sich den USB sparen :-)
Aber so ein Verhalten (Power-On-Reset funktioniert nicht) habe ich tatsächlich noch nicht erlebt. Welche Firmware hast Du denn auf dem Board? Die ESPhome oder die von dewenni?

Grüße,
Daniel

mutex1980, 2024-07-01:
Das ist die von dewenni 4.1.0

DonCanDo, 2024-10-14:
Moin,

ich hab das Problem leider auch. Hattest du dann eine Lösung gefunden?

the78mole, 2024-11-29:
Nachdem es ein issue von dewenni gewesen zu sein scheint, schließe ich das hier...

Closed 2024-11-29.

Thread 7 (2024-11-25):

I have a version 0.0.5:

gtsy7, 2024-11-25:
you can send me the last one, I'll print it myself, otherwise I can't connect to the lan W5500 Ethernet
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

the78mole, 2024-11-25:
???

gtsy7, 2024-11-26:
can you send me the PCB file?

the78mole, 2024-11-26:
Please download KiCad (it's Open Source) and Export the files you need.

gtsy7, 2024-11-26:
where can I download it?

gtsy7, 2024-11-26:
> Загрузите KiCad (это ПО с открытым исходным кодом) и экспортируйте необходимые вам файлы.

ок thanks

the78mole, 2024-11-26:
From this repo?

Closed 2024-11-29.

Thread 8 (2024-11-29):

what denomination should I use

gtsy7, 2024-11-29:
what denomination should I use
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

the78mole, 2024-11-29:
"np" means, "not populated". It is optional and you can populate it when you have something special in mind. E.g. R13, R14, R15, R16, and R53 are part of the GPIO input circuitry, where you can have flexible divider settings to address different input voltages and filtering or pull-up, pull-down,...

gtsy7, 2024-11-29:
> "np" means, "not populated". It is optional and you can populate it when you have something special in mind. E.g. R13, R14, R15, R16, and R53 are part of the GPIO input circuitry, where you can have flexible divider settings to address different input voltages and filtering or pull-up, pull-down,...

thank you very much

Closed 2025-08-08.

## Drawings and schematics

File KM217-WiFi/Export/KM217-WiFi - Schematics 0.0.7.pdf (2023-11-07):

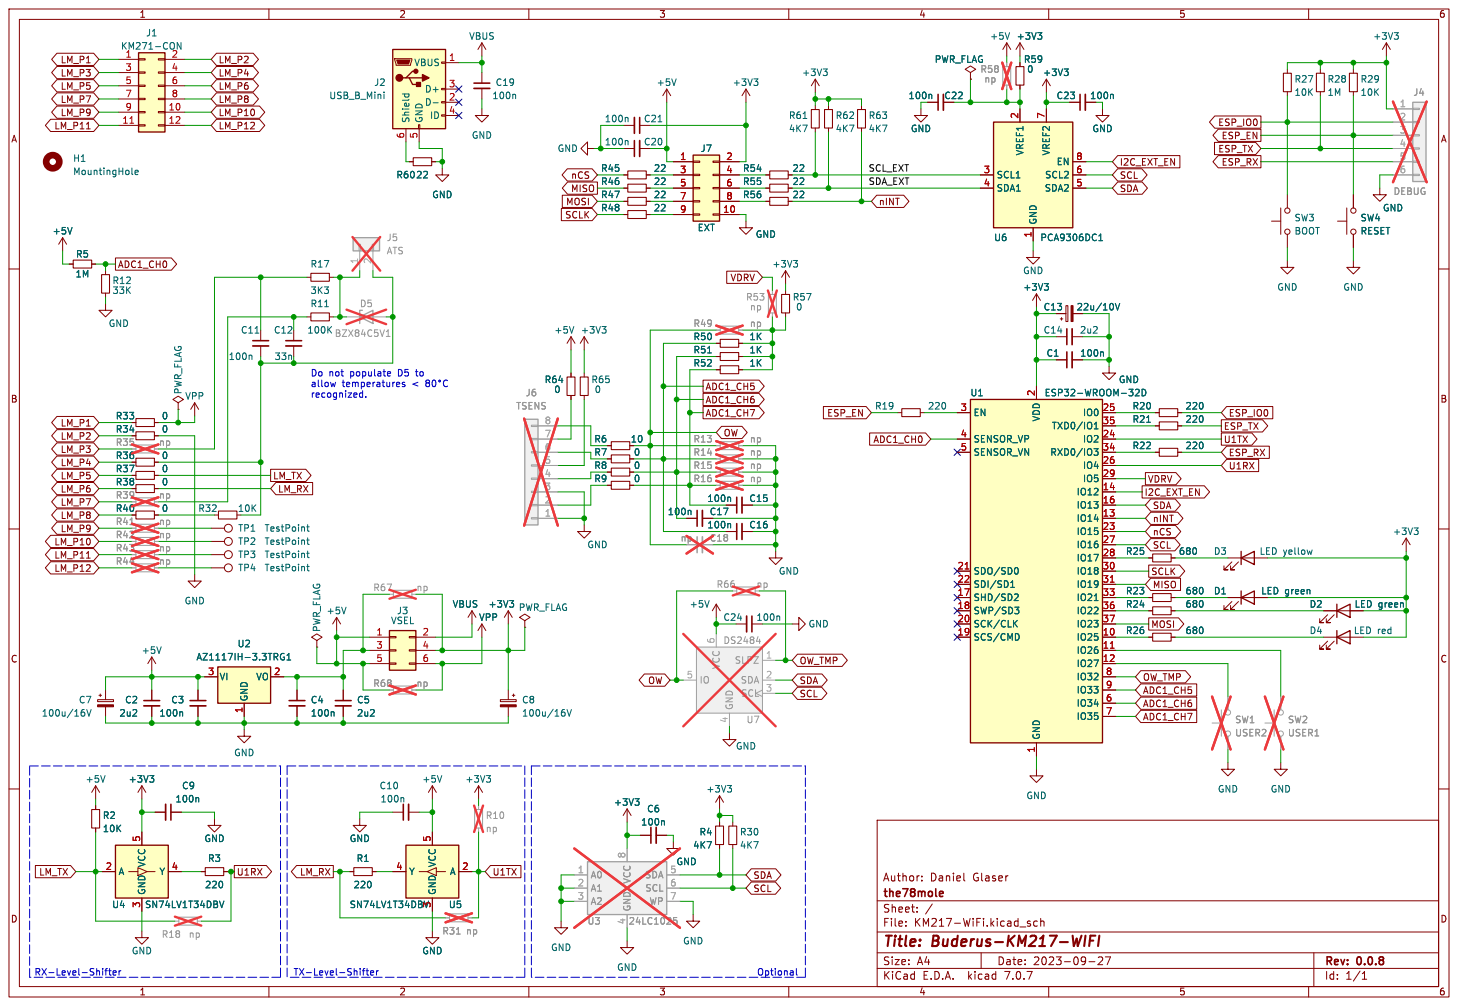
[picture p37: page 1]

2 SCK/CLK 20 SDO/SD0 21 SDI/SD1 22

1 VO 2 VI 3 U2 AZ1117IH-3.3TRG1 +3V3 GND GND

4 SDA 5 SCL 6 WP 7 VCC

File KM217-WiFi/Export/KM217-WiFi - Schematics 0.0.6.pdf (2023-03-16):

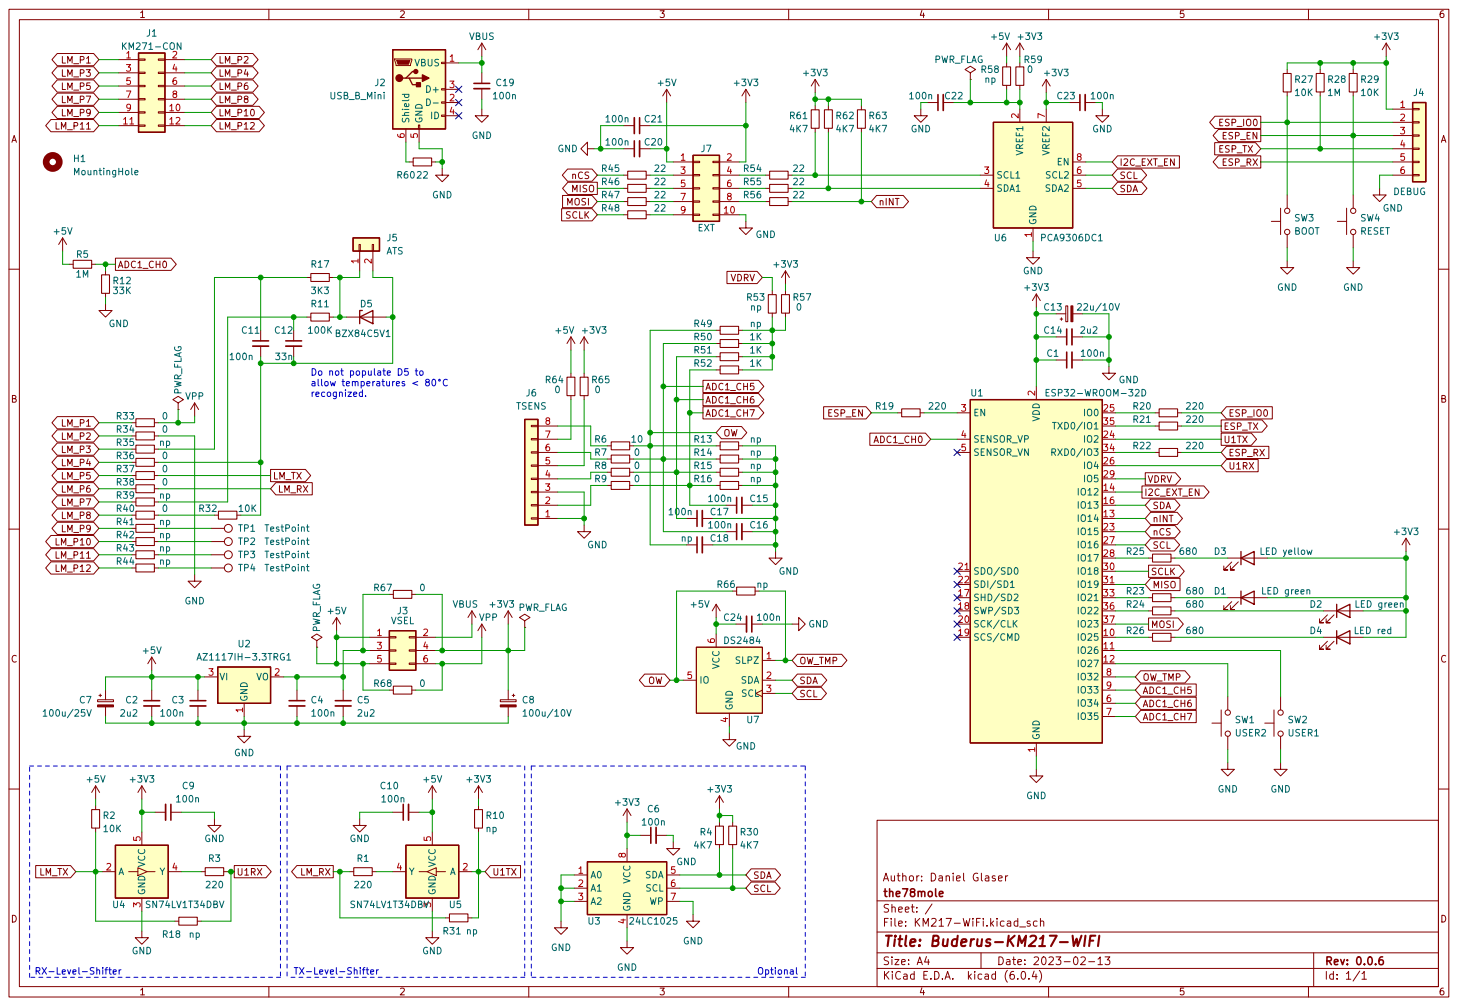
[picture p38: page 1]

Do not populate D5 to
recognized.

2 SCK/CLK 20 SDO/SD0 21 SDI/SD1 22

4 SDA 5 SCL 6 WP 7 VCC

File: KM217-WiFi.kicad_sch Sheet: / the78mole Author: Daniel Glaser

Id: 1/1 Title: Buderus-KM217-WIFI

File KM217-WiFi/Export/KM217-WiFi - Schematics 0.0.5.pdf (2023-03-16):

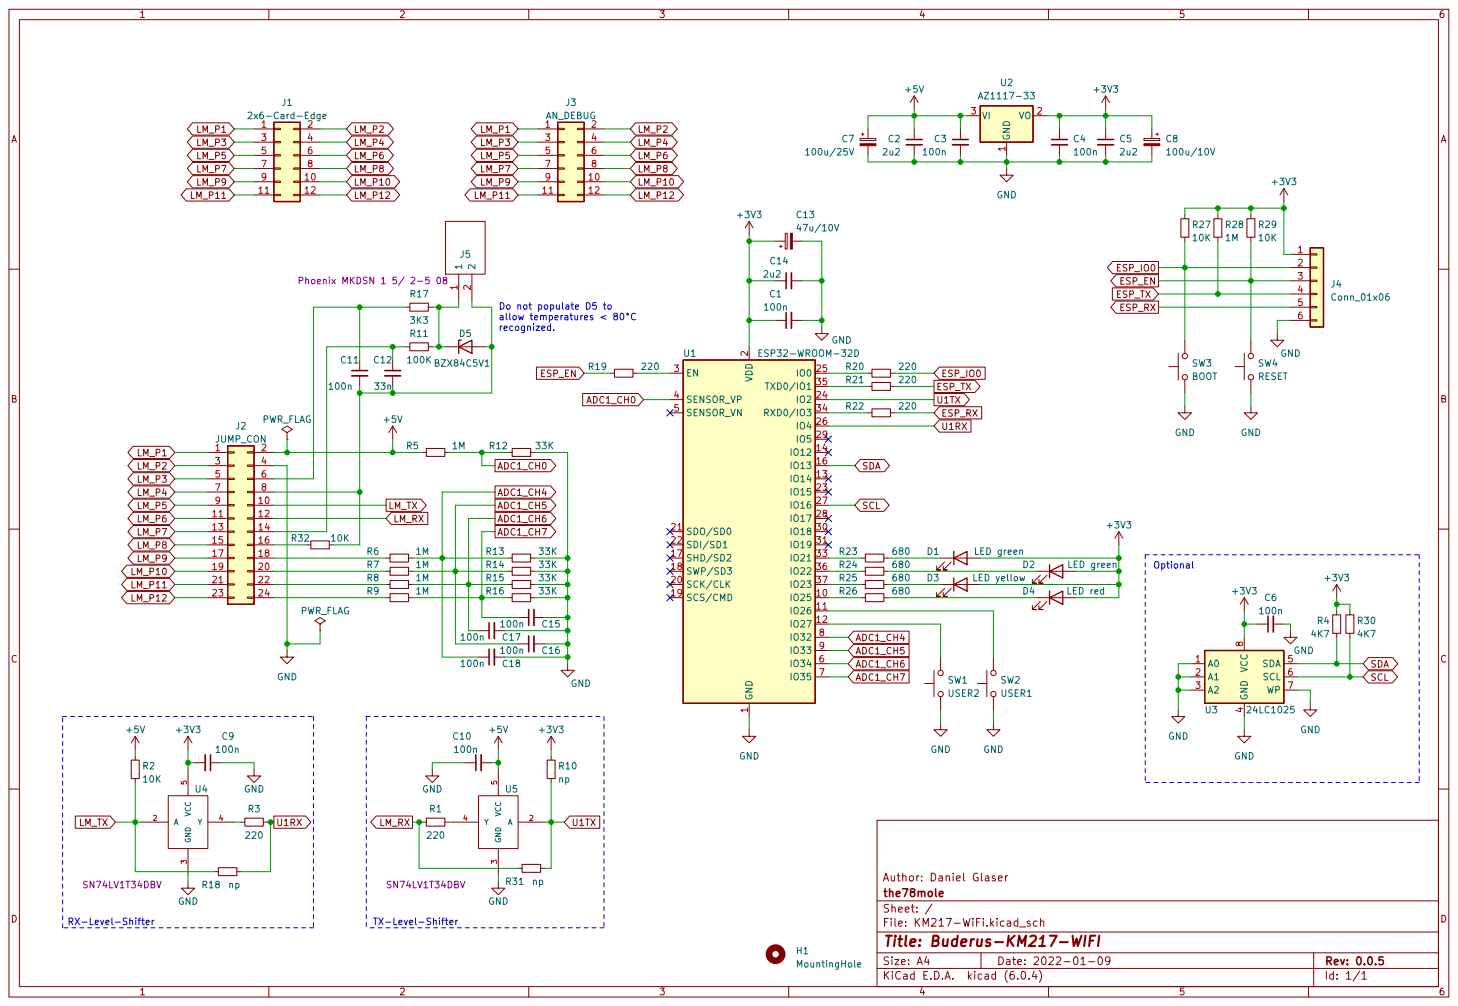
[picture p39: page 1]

2 SCK/CLK 20 SDO/SD0 21 SDI/SD1 22

R8 1M
R9 1M

4 SDA 5 SCL 6 WP 7 VCC

Id: 1/1 Title: Buderus-KM217-WIFI

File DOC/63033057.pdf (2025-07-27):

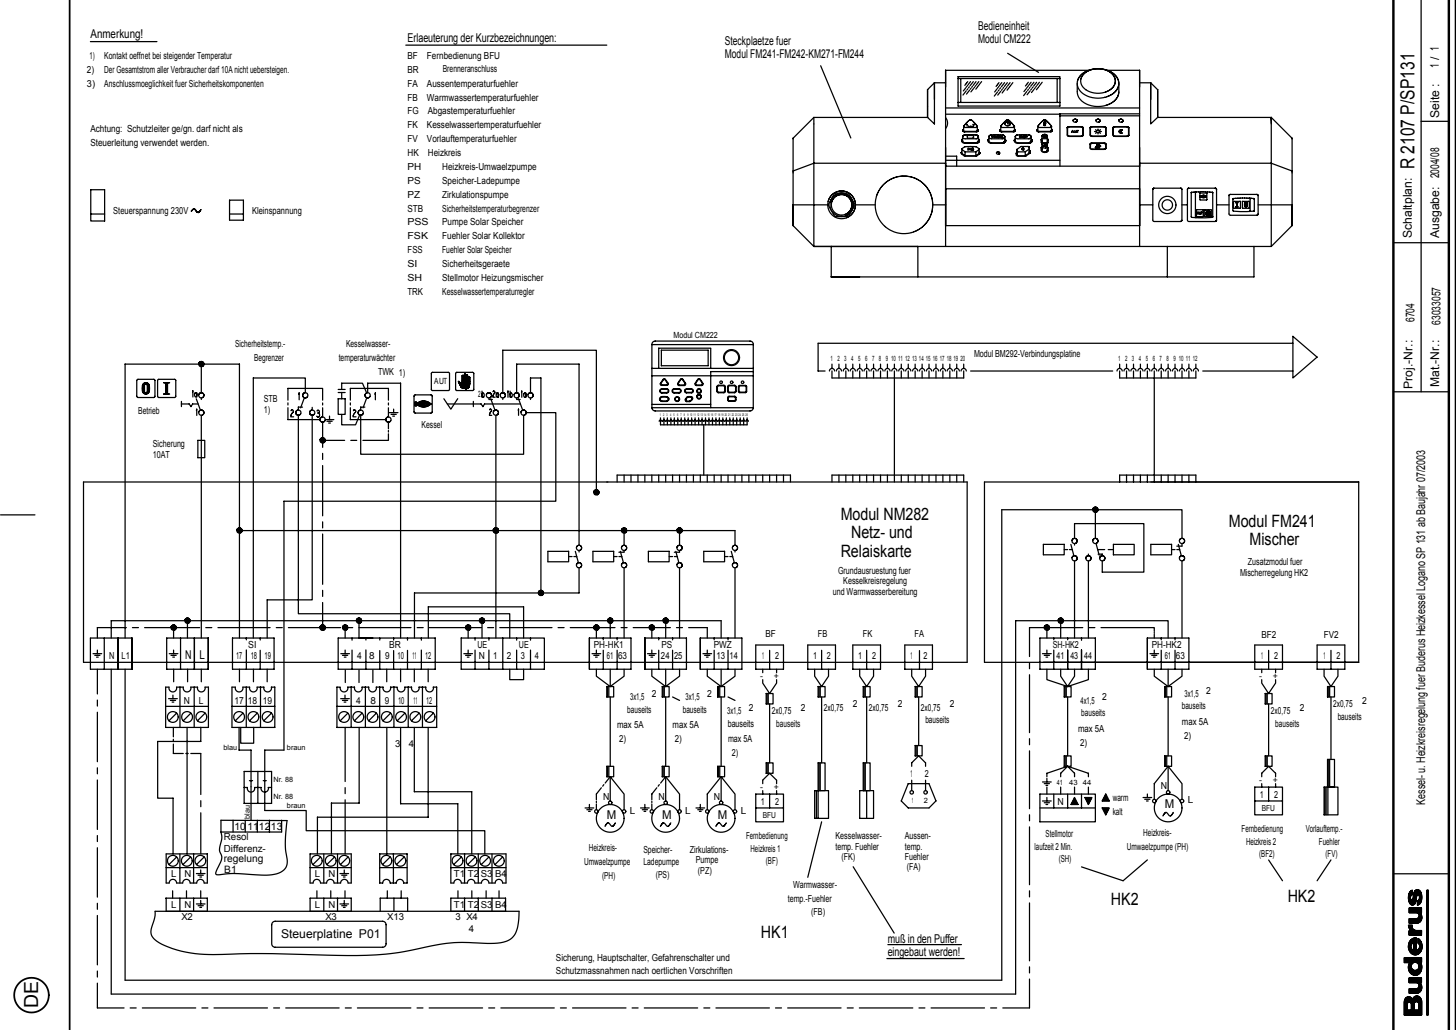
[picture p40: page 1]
Proj.-Nr.:; Mat.-Nr.:; Schaltplan:; Ausgabe:; Seite : /; Fuehler; Vorlauftemp.-; warm; kalt; laufzeit 2 Min.; Stellmotor; 3x1,5 bauseits; Umwaelzpumpe (PH); Heizkreis-; max 5A; 2 2x0,75 bauseits; Mischer; Modul FM241; Mischerregelung HK2; Zusatzmodul fuer; Heizkreis 2; Fernbedienung; BFU; Begrenzer; Sicherheitstemp.-; temperaturwächter; Kesselwasser-; Betrieb; Umwaelzpumpe; Kessel; Heizkreis 1; Relaiskarte; Netz- und; Modul NM282; Ladepumpe; Speicher-; Anmerkung!; und Warmwasserbereitung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

Erlaeuterung der Kurzbezeichnungen:
BF Fernbedienung BFU
FA Aussentemperaturfuehler
FB Warmwassertemperaturfuehler
FG Abgastemperaturfuehler
FK Kesselwassertemperaturfuehler
FV Vorlauftemperaturfuehler
HK Heizkreis

Kontakt oeffnet bei steigender Temperatur
Der Gesamtstrom aller Verbraucher darf 10A nicht uebersteigen.
Anschlussmoeglichkeit fuer Sicherheitskomponenten

Achtung: Schutzleiter ge/gn. darf nicht als
Steuerleitung verwendet werden.

Kessel- u. Heizkreisregelung fuer Buderus Heizkessel Logano SP 131 ab Baujahr 07/2003

muß in den Puffer
eingebaut werden!

Sicherung, Hauptschalter, Gefahrenschalter und
Schutzmassnahmen nach oertlichen Vorschriften

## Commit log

2021-07-26 As produced, added bom
    [KM217-WiFi.kicad_pcb]
2021-07-27 Corrected the KM217 connector (missedconfigured the bottom copper pins mask)
    [KM217-WiFi.kicad_pcb]
2021-07-27 Fixed an issue with the card edge connector
    [KM217-WiFi.kicad_pcb]
2021-07-27 Save bump :-(
    [KM217-WiFi.kicad_pcb]
2021-07-30 Added CSV BOM
    [KM217-WiFi.csv]
2021-08-05 Fixed the right edge to fit into the Buderus Control unit
    [KM217-WiFi.kicad_pcb, KM217-WiFi.kicad_sch]
2021-11-13 Added two larger Caps due to stability Problems of the ESP32.
    [KM217-WiFi.kicad_pcb, KM217-WiFi.kicad_sch]
2021-11-15 Minor changes (documentational)
    [KM217-WiFi.kicad_sch]
2021-11-21 Updated the PCB and BOM
    [KM217-WiFi.kicad_pcb]
2021-12-02 Upgrade to Revision 0.0.3
    - Added two potential detection resistors, R32 is the one that should be soldered for the LM 2107 controller to detect the KM271
    [KM217-WiFi.kicad_pcb, KM217-WiFi.kicad_sch]
2021-12-02 Upgrade to Version 0.0.4
    - Switched LM_RX and LM_TX
    [KM217-WiFi.kicad_pcb, KM217-WiFi.kicad_sch]
2022-08-15 Update to HW version 0.0.5 including exhaust temperature sensor
    [KM217-WiFi.kicad_pcb, KM217-WiFi.kicad_sch]
2022-10-04 Some updates on the components for production and assembly (BOM)
    [KM217-WiFi.kicad_pcb, KM217-WiFi.kicad_sch]
2022-10-12 As ordered 2022-10-12
    [Bauteil-Zusammenstellhilfe.ods, KM217-WiFi.csv]
2022-10-27 Added a license and updated some assembly information
    [KM217-WiFi.kicad_pcb, KM217-WiFi.kicad_sch]
2022-11-03 Added the most simple test program
    This is flashed on the board, when no firmware is ordered.
2022-11-07 Added the fully assembled picture
2022-11-28 Updated the ESPhome YAML config and informational changes to the HW design files
    [KM217-WiFi.kicad_pcb]
2023-02-14 Upgrade to Hardware Revision 0.0.6
    [KM217-WiFi.csv, KM217-WiFi.kicad_pcb, KM217-WiFi.kicad_sch]
2023-03-16 Cleaned up and added information
    [KM217-WiFi.csv]
2023-03-18 Made YAML work again and added firmware images
    When using esptool, take the km271-for-friends-factory.bin. Use following command line:
    <Path-to-esptool>\esptool.exe --chip esp32 --port <YOUR_COM> --baud 921600 write_flash -z 0x0 km271-for-friends-factory.bin
2023-03-19 Added detailed hardware description
    [KM217-WiFi.kicad_sch]
2023-09-16 Upgrade to 0.0.7
    - Changed ELKOs to SMD types (for assembly)
    - Added some more part numbers and included in assembly
    [KM217-WiFi.csv, KM217-WiFi.kicad_pcb, KM217-WiFi.kicad_sch]
2023-09-26 Upgrade to KiCad version 7.0
    [KM217-WiFi.kicad_sch]
2023-09-27 Updated 0.0.7
    [KM217-WiFi.kicad_pcb, KM217-WiFi.kicad_sch]
2023-09-27 Updated KiCad page properties
    [KM217-WiFi.kicad_sch]
2023-11-07 Updated to version 0.0.7 as available since 2023-11-07
    [KM217-WiFi.kicad_pcb]
2024-02-26 Update to 0.0.8 as ordered on 2024-02-26
    [KM217-WiFi.kicad_sch]
2024-02-26 Order placed for 0.0.8
    [KM217-WiFi.kicad_pcb]
2024-06-02 Updated FW dewenni and scripts for flashing
    [KM217-WiFi.kicad_sch]
2024-06-02 Added first signs and docs of a future wired ethernet module
2025-01-13 Check-In as latest PCB Order
    - Changed CH7 input circuitry to match oil counters requirements (pull-down, 5V tolerant resistor divider)
    - Minor cosmetics
    - Bumped to version 0.1.0
    [KM217-WiFi.kicad_pcb, KM217-WiFi.kicad_sch]
2025-01-13 Added ETH W5500 Extension Board
    [ETH_W5500.kicad_pcb, ETH_W5500.kicad_sch]
2025-01-15 Cleaned up parts data (MPN, DNP,...)
    [KM217-WiFi.kicad_pcb, KM217-WiFi.kicad_sch]
2025-03-09 Update to KiCad 9.0
    [KM217-WiFi.kicad_pcb, KM217-WiFi.kicad_sch]
2025-04-18 Improve documentation and ETH-Extension
    [ETH_W5500.kicad_pcb, ETH_W5500.kicad_sch]
2025-05-27 Added ADC calibration to README.md
    The ESP32 ADC needs some calibration because it is quite far of when factory calibration is used. Added a description, how to calibrate when using ESPhome.
2025-07-27 Feature/merge local improvements (#12)
    * Added some flash helpers and updated whole repo
    * Prepare workflow for firmware release compilation
    * Refactor code structure for improved readability and maintainability
    * Removing old HW Design
    * Add Erste Schritte documentation PDF
    * Add script for final Renovate coverage test
    * Implement code changes to enhance functionality and improve performance
    * Add discussion and issue templates for community engagement and support
    * Add Pogo-Frame CAD files for mechanical design
    * Version Bump PCB (added I2C Bridge again).
    [3d-helper.FCStd, Bauteil-Zusammenstellhilfe.ods, Holder.FCStd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]
2025-07-28 Add GitHub Actions workflows for PR checks and hardware release (#14)
    🛠 GitHub Actions & KiCad Automation Updates
    - CI/CD Workflows: Added pr-check.yml and release.yml for KM217-WiFi and ETH_W5500 with build, validation, and artifact export.
    - Optimierung: Build-Skripte prüfen auf Änderungen seit letztem Release und überspringen unnötige Builds.
    - Revision Handling:
    * Automatische Revisionserkennung für JSON, S-Expression und XML
    * PR-spezifische Revisionen im Format 1.2.3-pr42
    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
    [ETH_W5500.kicad_pcb, ETH_W5500.kicad_sch, KM217-WiFi.kicad_pcb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]
2025-09-28 Update workflow to use kicaddev 1.5.0 docker image from @the78mole/docker-images (#15)
    * Update workflow to use kicaddev 1.5.0 docker image from @the78mole/docker-images
    ---------
2025-09-28 Refactor PCB export script to combine individual layer PDFs into a single output file (#16)
    * Refactor PCB export script to combine individual layer PDFs into a single output file
    * chore: update kicaddev Docker image to version 1.6.0 across all configurations
